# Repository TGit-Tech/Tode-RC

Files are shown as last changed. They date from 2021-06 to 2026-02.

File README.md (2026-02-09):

-----------------------------------------------------------------------------------
# Tode-RC
-----------------------------------------------------------------------------------
A User-Interfaced Arduino Mega Pro with Ebyte LoRa Radio.\
It's like a RF-Node but call it a 'Tode'.

- Arduino Mini Mega 2560 compatible Micro-Controller
- 1.8" TFT Display and 6-Button Keypad
- User friendly On-Controller IO configuration

See the docs/ Users-Guide for device support list and usage details including MQTT OpenHab connection abilities.

Benefits of the Tode over ESP32 LoRa Modules
- Big enough to be practical.  Small enough to be handy.
- 5V TTL-IO (Ebyte-RF 5V match, 200mW/IO power, Ready-fit for 5V Sensors)
- 54-IO pins (leaving (46) with display, keypad, radio connected)
- 30dbm (T30D) Transmission Power with Ebyte LoRa Modules (A good 5-mile distance)
- 3-Piece plug-together assembly keeps individual parts easy to swap/salvage.

Due to button sticking issues the buttons are now just black tops shown in first image.

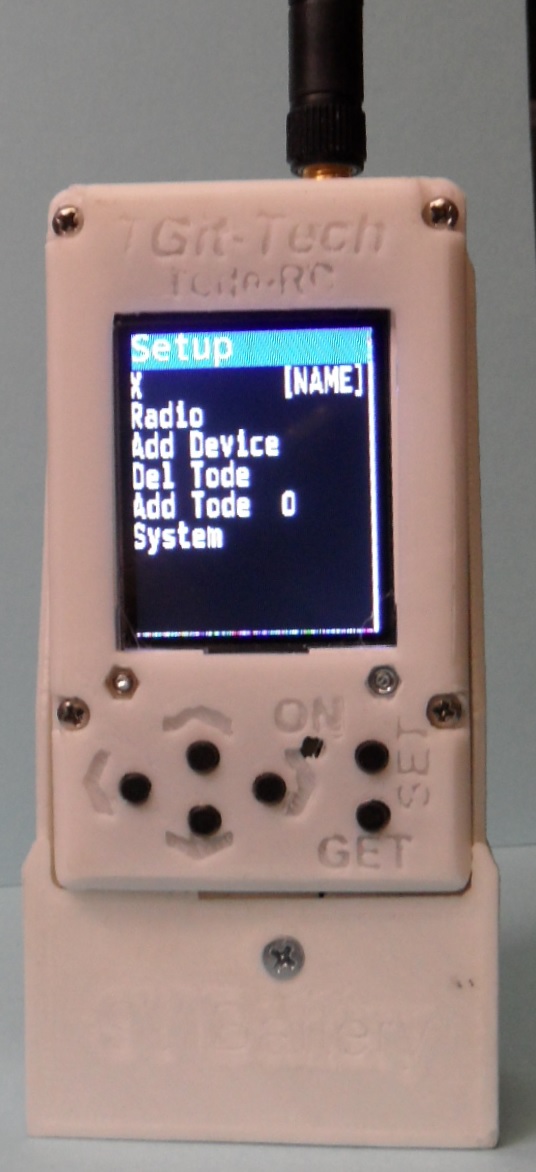
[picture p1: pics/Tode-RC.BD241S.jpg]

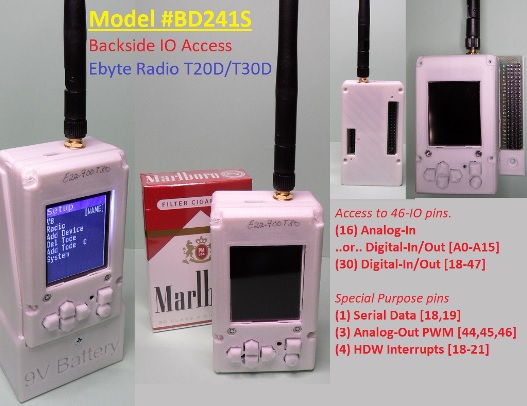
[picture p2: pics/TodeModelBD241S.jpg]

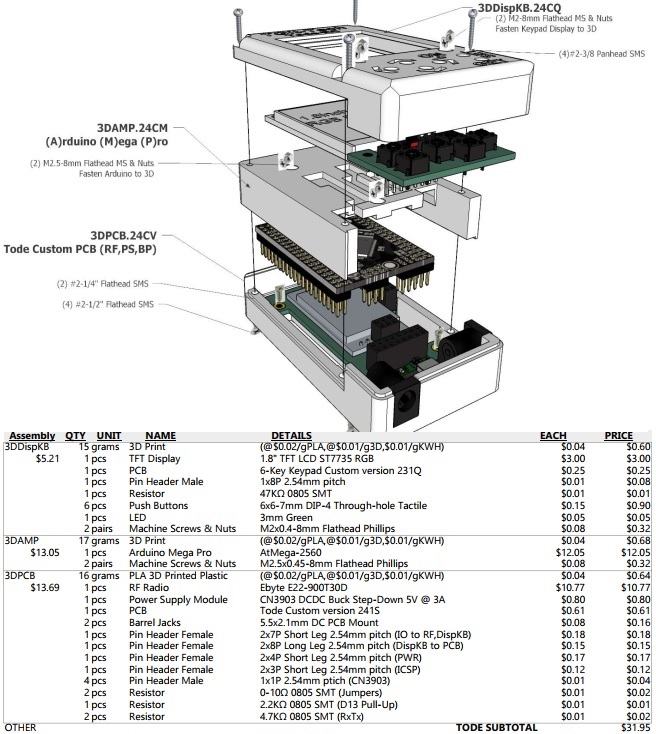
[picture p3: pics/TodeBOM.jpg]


-----------------------------------------------------------------------------------
#Project Purchase Options
-----------------------------------------------------------------------------------
Purchase pre-made at...
- https://www.tindie.com/stores/tgittech/
- https://www.etsy.com/shop/TGitTech

-----------------------------------------------------------------------------------
#Project Firmware & Expansions
-----------------------------------------------------------------------------------
- Firmware at https://github.com/TGit-Tech/Tode-RC-Firmware
	- Be sure to set Backplane model in config.h
- Side-IO Screw Terminals #SIOST (pictured) https://github.com/TGit-Tech/Tode-IO
- Back-IO Pin Header Array #BIOPH https://github.com/TGit-Tech/Tode-IO

-----------------------------------------------------------------------------------
#Project Status
-----------------------------------------------------------------------------------
USE Tode-RC.BD241S.  It supports 1W(T30D) or 1/4W(T20D) Ebyte Radios.\
Double Check that the PCB doesn't have the below design error.

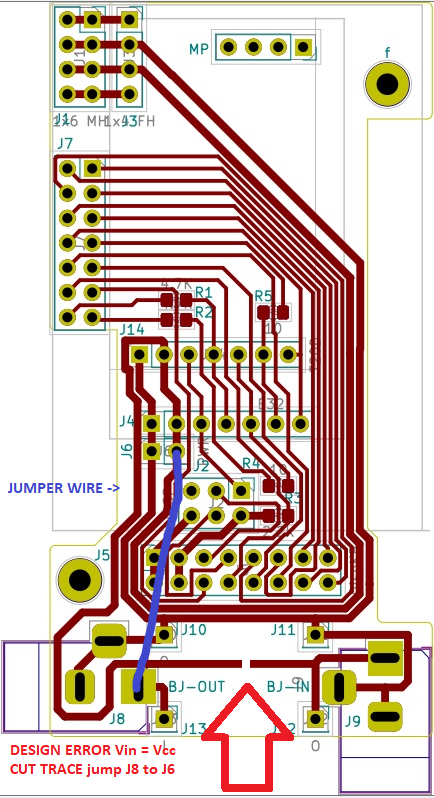
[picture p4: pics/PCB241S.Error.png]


Model SD23CF(In-Design/BETA) supports 2W(T33D) Radios but only 7-IO pins.
	
- Previous Release Notes
NEW changes.  The old model SA212K with analog keypad will become obsolete (not supported).
All future designs will have digital keypads as analog was spotty with moisture and 
temperature change.  Secondary Power Supplies are On-PCB now for both SD23CF(Side-IO) 
and BD241S(Back-IO).  Firmware will auto-detect E32-433T20D/T30D, E22-400T30D/900T30D 
and E220-400T30D Ebyte Radios.

---

# 🌐 **Tode Ecosystem**

The Tode Ecosystem offers a robust, flexible, and secure solution for managing devices in an environment where **infrastructure is not required**. It’s designed to seamlessly integrate with the **RF-DITS** protocol, providing a communication framework for device control, alarm propagation, and security.

## 🚀 **Overview**

The Tode Ecosystem empowers devices to function autonomously or in **P2P** (peer-to-peer) networks, providing an **infrastructure-free solution** for industrial, home, and remote applications. With its **5V EMT-resistant hardware** and powerful **virtual device** logic for alarm processing, it brings resilience and versatility to the edge of your network.

---

## 🛠️ **Key Features**

* **Non-Infrastructure Communication**: Operates **without** requiring an internet connection, server, or cloud dependencies. Devices communicate **peer-to-peer** between nodes, allowing for seamless data exchange and control.

* **RF-DITS Protocol**: The core communication protocol used by the Tode ecosystem. This protocol allows secure, fast, and efficient communication between Master and Remote nodes using **Device Index Tables (DIT)** with integrated security.

* **5V EMT Resistance**: Built to handle harsh environments, the Tode ecosystem is engineered to withstand **electromagnetic interference (EMI)**, providing reliable operation in industrial settings.

* **Virtual Device Logic**: The **Virtual Device Logic** allows users to implement custom control logic directly on the device, enabling real-time alarm processing, device manipulation, and other control functions.

* **Quick Firmware Updates**: The firmware can be quickly updated by plugging the Tode node into a wiring interface, making updates straightforward without requiring specialized equipment.

---

## 🔒 **Security**

* **SecNet (Security Network)**: The Tode ecosystem utilizes **SecNet**, a user-set security code embedded in each packet. This ensures data integrity and security. The **SecNet** code is also used as part of a challenge-response mechanism during **SETVAL** operations, preventing replay attacks and ensuring secure value updates.

* **Packet Integrity**: Every packet transmitted in the Tode network is verified for authenticity with the **SecNet** code. Only authorized devices can send or receive data securely. **SETVAL** operations are particularly secured to ensure legitimate communication.

* **Alarm Security**: Alarm messages are pushed to the designated **Remote nodes** when a condition is triggered. The **SecNet** code ensures that only authorized recipients receive the alarm notifications.

---

## ⚡ **Quick Setup & Control**

* **Device Setup**: The Tode ecosystem doesn’t require centralized infrastructure or cloud servers. Each **Master node** stores the configuration of its attached devices and is capable of sharing this configuration with **Remote nodes** using the **RF-DITS protocol**. **Remote nodes** can pull configurations and control devices according to those settings.

* **Time-Sensitive Updates**: Alarm conditions are pushed immediately to all **Remote nodes** without unnecessary overhead. Value updates can be requested by the remote node through the **RF-DITS protocol**, ensuring efficient communication.

---

## 📈 **Key Advantages Over Common IoT Platforms**

| **Key Advantage** | **Tode Ecosystem (RF-DITS)** | **Common IoT Platforms** |
| --- | --- | --- |
| **Infrastructure** | Operates **without** internet or server dependencies, functioning in **peer-to-peer** mode. | Requires cloud, servers, or centralized hubs for device control |
| **Portability** | **Portable** control with remote nodes in P2P communication. | Typically dependent on fixed infrastructure |
| **Data Integrity** | Secured communication with **SecNet** protecting packets and ensuring valid data exchange. | Often lacks robust security or packet verification |
| **Low Airtime Communication** | Optimized communication with **DIT** table, reducing airtime usage for value exchanges. | Typically uses more airtime due to polling systems and continuous communication |
| **Alarm Handling** | **One-time push** of alarms to Remote nodes, minimizing network traffic. | Continuous polling for alarm conditions, leading to higher network usage |
| **Device Control** | Full **control** over devices with direct value setting, updating, and logic processing. | Remote devices may be read but not easily controlled depending on the platform  |
| **EMT Resistance** | Designed to handle **electromagnetic interference (EMI)** in industrial environments. | Sensitive to environmental EMI interference, which can disrupt performance |
| **Firmware Updates** | **Easy and fast** firmware updates via a wiring interface—no internet or specialized equipment needed. | Over-the-air updates typically require internet access and cloud dependencies |
| **Flexible Control Logic** | **Virtual device logic** allows for custom control and alarm processing locally on the device. | Often lacks flexibility for local control and relies on cloud logic |

---

## ⚙️ **Protocol Breakdown: RF-DITS**

### **Device Index Table with Security (DITS)**

Each node maintains a **Device Index Table (DIT)** that lists the connected devices by index. This table helps the **Master node** store and transmit configurations for each attached device to **Remote nodes**.

* **Master Node**: Stores and manages the configuration of devices, pushes alarm notifications, and shares device settings with **Remote nodes**.
* **Remote Node**: Pulls device configurations from the **Master node** and can manipulate values according to the stored configuration.

### **Alarms**

* **Alarm Handling**: When an alarm condition is triggered on the **Master node**, an alarm packet is sent to all **Remote nodes** on the recipient list.
* **No Acknowledgment Required**: The alarm is a **one-time push** with no response required from the **Remote nodes**.
* **Alarm Recipient List**: The **Master node** stores a list of **Remote node** addresses, which is dynamically updated with each communication, including value requests. Manual pruning of the list is also possible.

---

## 🔗 **Integration with External Systems**

While the Tode ecosystem operates **without the need for internet infrastructure**, it can optionally integrate with systems such as **MQTT**, **OpenHAB**, or **Home Assistant** through an MQTT bridge.

This optional feature allows:

* **Pulling Device Values**: Remote nodes can request device values from **Master nodes** on a regular schedule or based on events.
* **Pushing Alarms**: When an alarm condition is triggered, the **Master node** can push the alarm data to an MQTT broker, which allows external systems to act on the alarm.

However, it's important to note that **Tode's core functionality** works without cloud connectivity, and the MQTT integration is entirely optional.

---

## 🔑 **Hardware Advantages**

Tode nodes are designed to operate in **industrial environments** where **electromagnetic interference (EMI)** is common, and devices need to withstand harsh conditions. The **5V EMT-resistant hardware** ensures the Tode ecosystem works reliably even in settings that may disrupt other IoT systems.

---

## 🛠️ **Getting Started**

1. **Set Up the Master Node**: Connect and configure devices on the **Master node**. Store configurations and define which devices you want to control.
2. **Add Remote Nodes**: Manually enter the **Master node's** address into the **Remote nodes** to establish communication and pull device configurations.
3. **Manage Alarms and Control**: Configure alarm conditions on the **Master node**. Alarms will be **pushed** to all **Remote nodes**.
4. **Firmware Updates**: Simply plug the Tode node into the wiring interface to update its firmware without requiring internet access.

---

## 📚 **Conclusion**

The **Tode Ecosystem** offers a resilient, flexible, and secure solution for edge-device control in environments where **infrastructure** is not an option. Its core **RF-DITS protocol** and **5V EMT resistance** provide reliable communication, while its optional integration with systems like **MQTT** makes it versatile for a range of applications.

---

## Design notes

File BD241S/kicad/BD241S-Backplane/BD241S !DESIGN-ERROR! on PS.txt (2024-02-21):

The Input voltage traces to VCC.
It can be cut and then add a jumper wire from P.S. out to VCC.

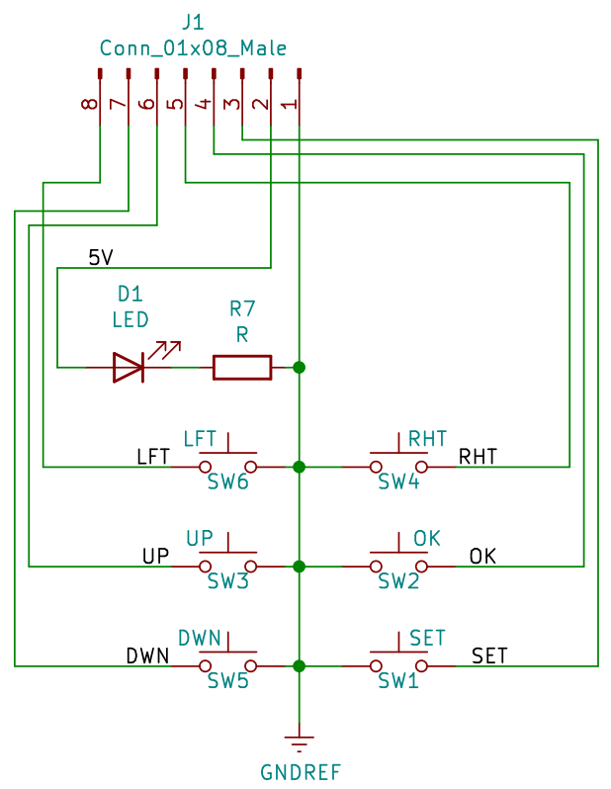
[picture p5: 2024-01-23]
BD241S/kicad/Tode-Buttons-D231Q/Schematic.png

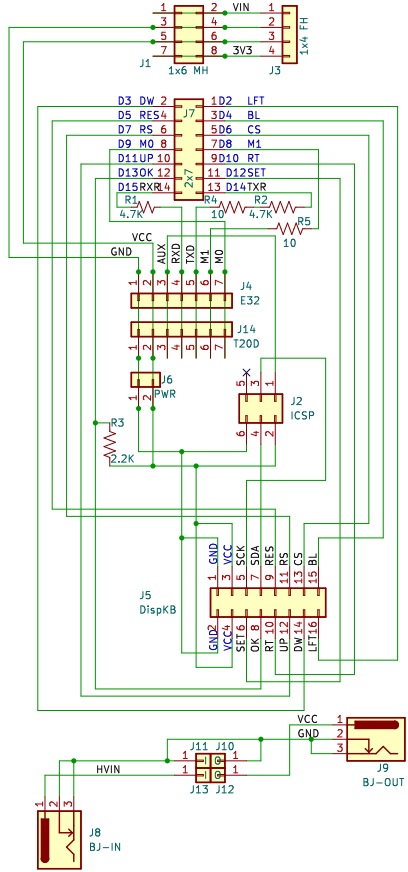
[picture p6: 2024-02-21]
BD241S/kicad/BD241S-Backplane/241S-Schematic.jpg

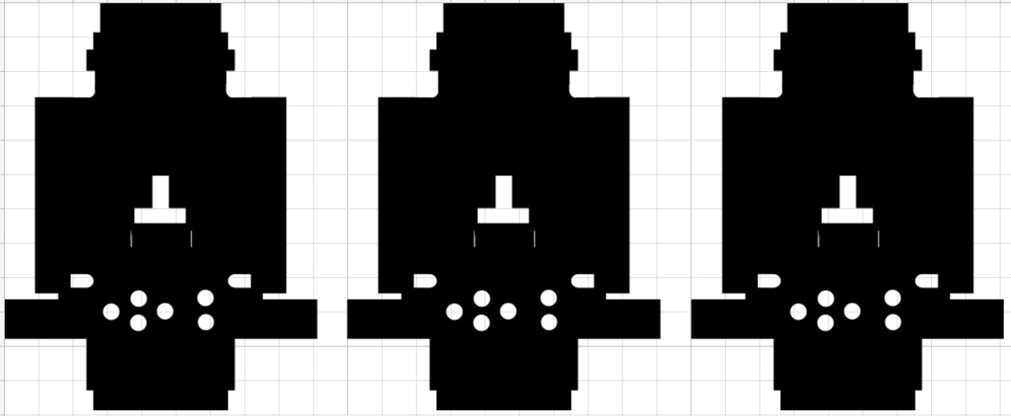
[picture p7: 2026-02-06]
docs/CriCut-Decal-Laminate.jpg

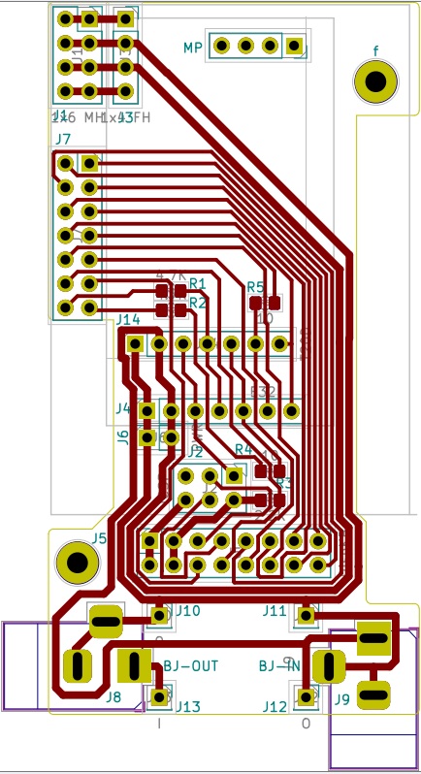
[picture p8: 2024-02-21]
BD241S/kicad/BD241S-Backplane/241S-Layout.jpg

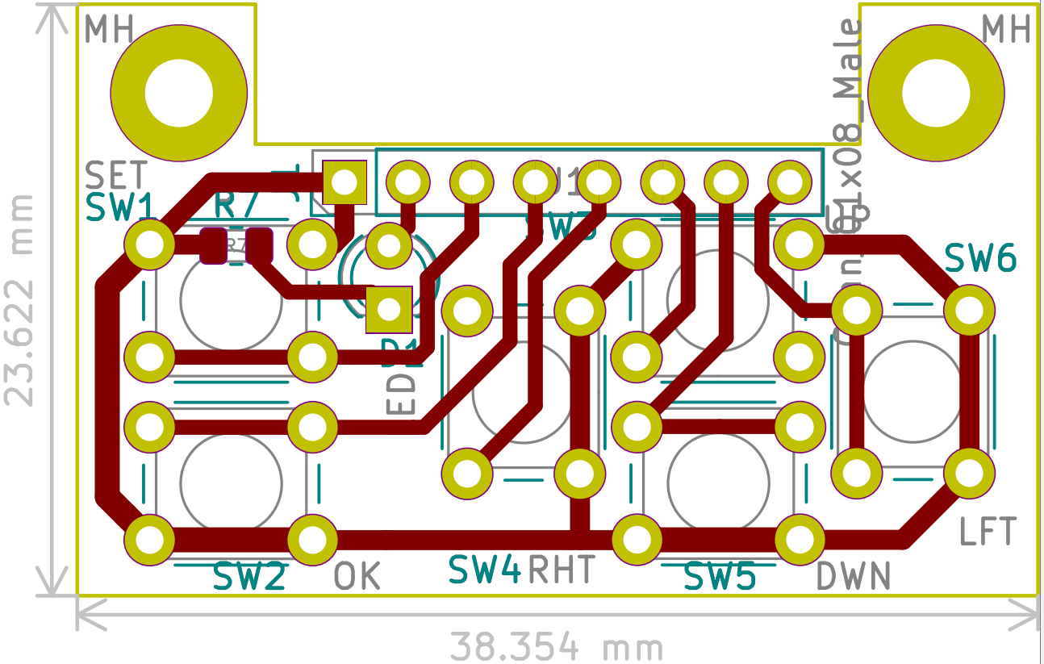
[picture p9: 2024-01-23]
BD241S/kicad/Tode-Buttons-D231Q/Layout.png

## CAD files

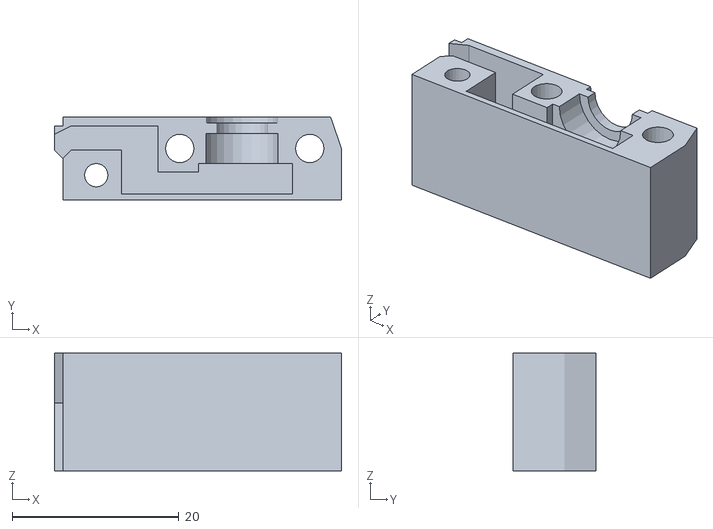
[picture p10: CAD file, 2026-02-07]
BD241S/3DPrints/9V1W.3DClamp.24CV.stl
34.4 x 10.0 x 14.1

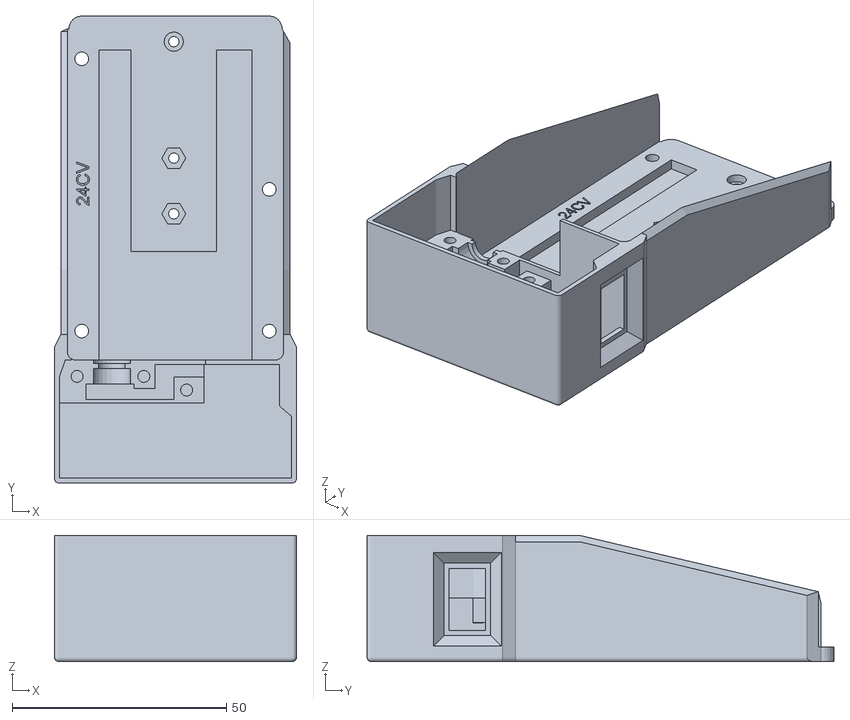
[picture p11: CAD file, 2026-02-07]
BD241S/3DPrints/9V1W.3DTray.24CV.stl
56.5 x 109.1 x 29.5

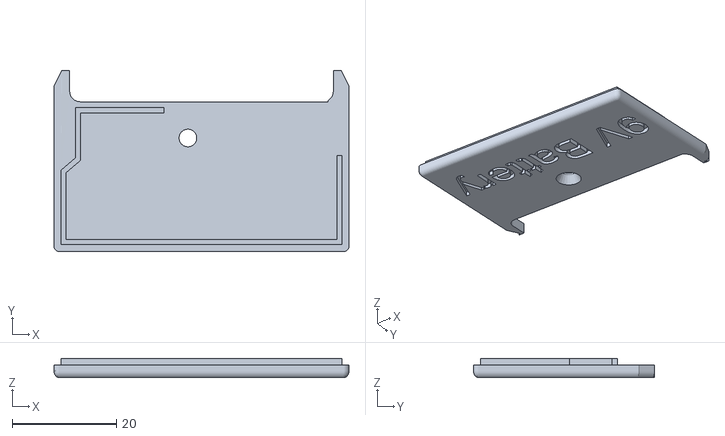
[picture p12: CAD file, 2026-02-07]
BD241S/3DPrints/9V1W.3DCover.2627.stl
56.6 x 34.7 x 3.70

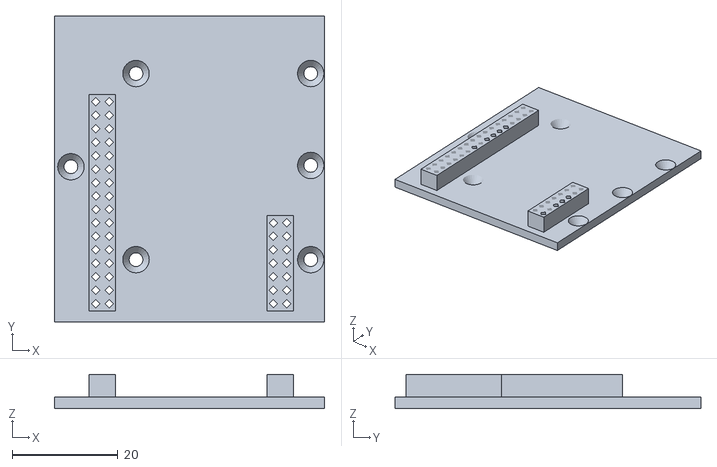
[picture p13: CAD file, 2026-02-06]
BD241S/3DPrints/BIOPH.FrontSide.249Q.stl
51.0 x 57.8 x 6.50

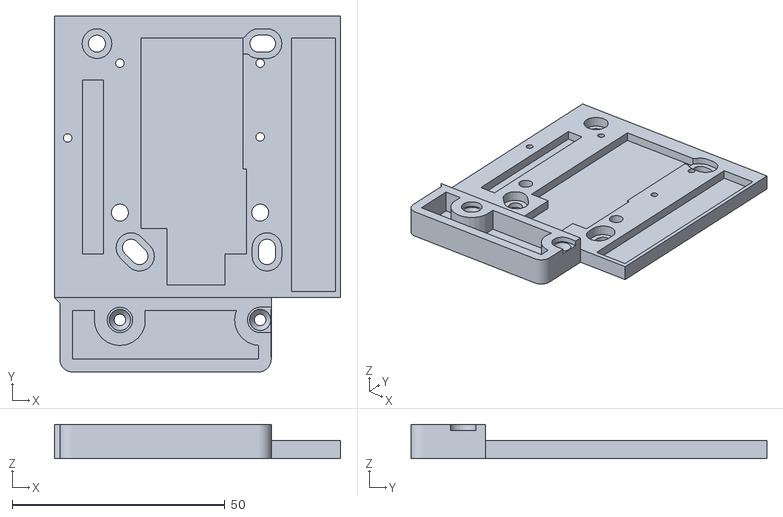
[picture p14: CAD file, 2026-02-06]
BD241S/3DPrints/BIOPH.BackSide.261C.stl
67.3 x 83.8 x 8.06

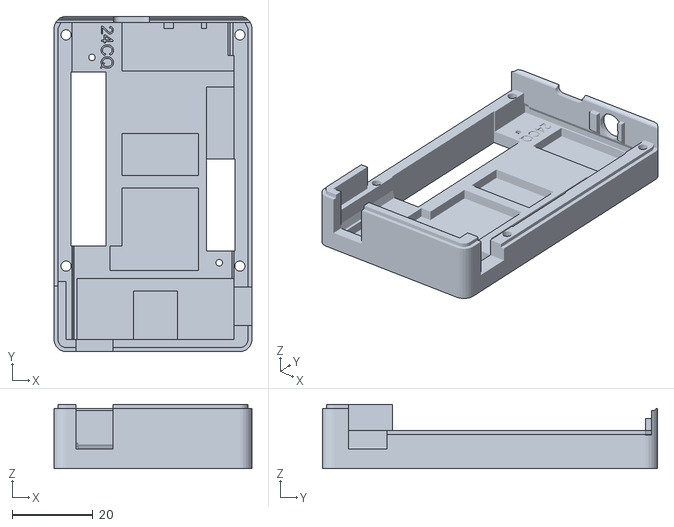
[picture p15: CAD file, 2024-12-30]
BD241S/3DPrints/BD241S.3DPCB.24CQ.stl
49.0 x 83.0 x 15.9

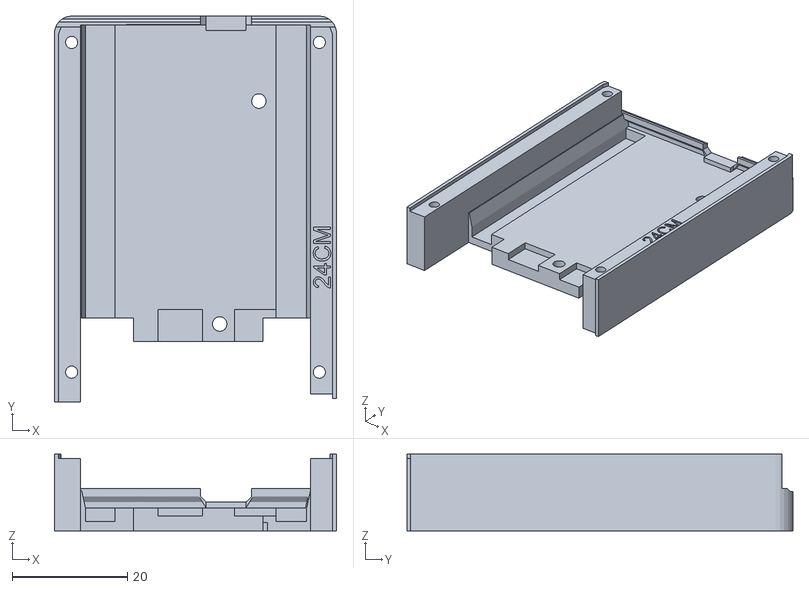
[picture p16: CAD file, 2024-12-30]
BD241S/3DPrints/BD241S.3DAMP.24CM.stl
49.0 x 67.0 x 13.4

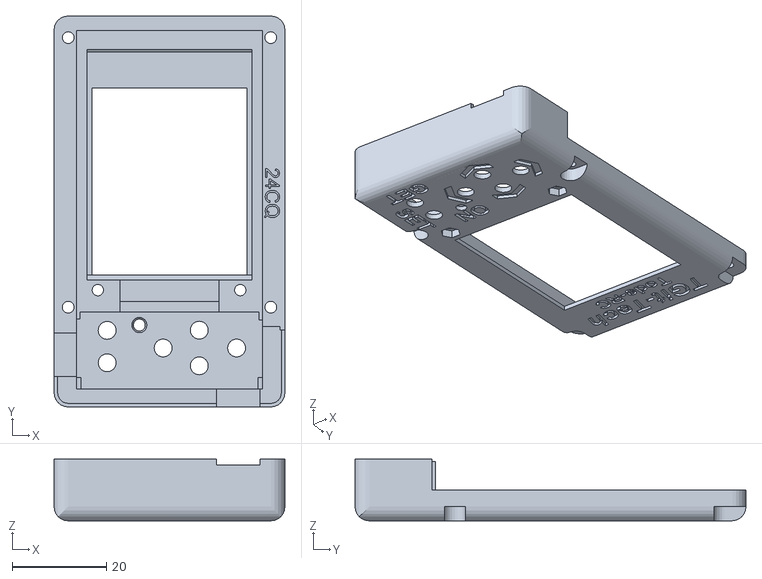
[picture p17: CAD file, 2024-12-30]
BD241S/3DPrints/BD241S.3DDispKB.24CQ.stl
49.0 x 83.0 x 13.1

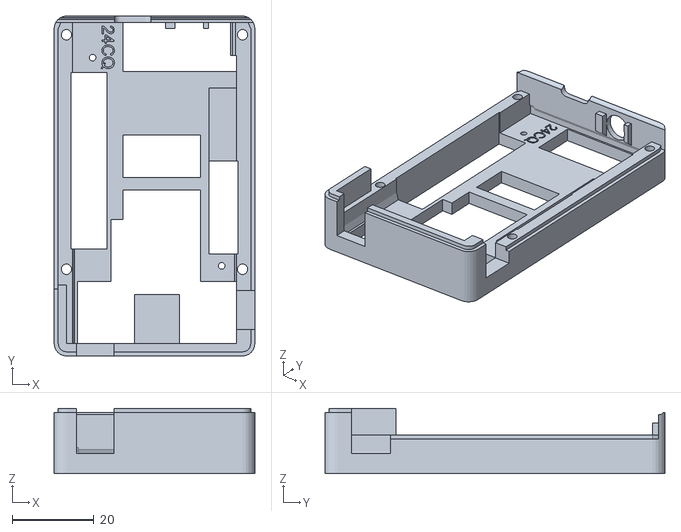
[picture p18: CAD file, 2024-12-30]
BD241S/3DPrints/TOOL.3DPCBSolderAlign.24CQ.stl
49.0 x 83.0 x 15.9

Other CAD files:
BD241S/3DPrints/skp/9V1W.3DClamp.24CV.skp
BD241S/3DPrints/skp/9V1W.3DCover.2627.skp
BD241S/3DPrints/skp/9V1W.3DTray.24CV.skp
BD241S/3DPrints/skp/BD241S.3DAMP.24CM.skp
BD241S/3DPrints/skp/BD241S.3DAssembly-Diagram.skp
BD241S/3DPrints/skp/BD241S.3DAssembly.skp
BD241S/3DPrints/skp/BD241S.3DDispKB.24CQ.skp
BD241S/3DPrints/skp/BD241S.3DPCB.24CQ.skp
BD241S/3DPrints/skp/TOOL.3DPCBSolderAlign.24CQ.skp

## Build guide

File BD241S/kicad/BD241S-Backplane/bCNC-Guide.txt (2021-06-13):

QUICK GUIDE
notation = [Menu-bar].{section}/=Ribbon=."Button"
----------------------------------------------------------------------------
1.	Run bCNC
2.	[FILE].{Serial}.set-COM."Open"
3.	[CONTROL].{Status}."XYZ=0"
4.	[CONTROL].{Command}."G01 X22Y17 F300" ( variations - see #3 below )
6.	[CONTROL].{Control}."Z-down" till bit is close but not touching PCB
5.	[CONTROL].{Status}."XYZ=0"
4.	[PROBE].{Probe}."Probe"			( Req setup parameters first )
5.	Wait for 'Idle' then [CONTROL].{Status}."XYZ=0"
6.	[OPEN-FILE]icon.open-file
7.	[PROBE].=Autolevel=."Margins"
8.	[PROBE].{Autolevel} Set number of probes X & Y for ~ Step of 12
9.	[PROBE].=Autolevel=."Scan" (Big Button)
10.	Wait for 'Scan' to finish
11.	[PROBE].=Autolevel=."Zero"
12.	De-Wire the bit
13.	[CONTROL]."Start"
------------------------------------------------------------------
1. [CONTROL]  	Home + XYZ=0 + "G01 X22Y17 F300" + Z-Down-Close + XYZ=0
2. [PROBE]		Probe + XYZ=0												Probe Feed: 5.0
3. Load the File + Autolevel Margins + Scan									Z: Max: 0.5

vvvvvvvvvvvvvvvvvvvvvvvvvvvvvvvvvvvvvvvvvvvvvvvvvvvvvvvvvvvvvvvvvvvvvvvvvvvvvvvvvvvvvvvvvvvvvvvvvvv
1.  Setup
  a - Load a blank PCB onto the CNC Mill using 3D Printed Platform:
      "D:\Mechanical\ME - CNC-Milling\PCB-Mill-Platform\PCB-MillPlatform-100x70mm-Smoothed.stl"
  b - Load the Bit used for Trace Isolation
  c - Connect the Probe Wires to the Board and Bit
  d - Power up the CNC Mill
  e - Start bCNC

2.  Connect
  a - MENU 'File'
      -- 'Serial' -> 'Open'
      -- Check 'Connected' status & Positions are shown

3.  Homing
  a - MENU 'Control'
      -- Click 'Custom Button #5' or Command '$h'
      -- Click 'XYZ=0'
      -- In 'Command' Box (bottom-left) enter 'G01 X22Y17 F300'
          TEMP SPOT: 'G01 X57Y42 F300'
          -- Tightest X & Y = G01 X21.5Y16 F300
          -- Tightest X = G01 X21.5Y17 F300
          -- Tightest Y = G01 X22Y16 F300
      -- Click 'XY=0'
      -- Under 'Control' Press Z-Down 30
      -- VISUALLY check bit is in a good XY=0 position

4. Initial Z-Probe
  a - MENU 'Probe' - SUBMENU 'Common'
      -- Fast Probe Feed: 	100.0
	  -- Probe Feed: 		10.0
	  -- TLO:				0.000
	  -- Probe Command:		G38.2
  b - MENU 'Probe' - SUBMENU 'Probe'
      -- Set last box (Probe along Z-axis):   -10
      CLICK 'Probe'
      -- Click 'Z=0'
  
9. Open File
  a - MENU 'Open File' (Small folder icon top-left)

10. Autolevel Probe
  [[ PROBE - AutoLevel - Margins - Scan & PROBE - Probe - AutoLevel - Zero ]]
  a - MENU 'Probe' - SUBMENU 'Autolevel'
      -- Click 'Margins'
      ++ Under 'AutoLevel'
        -- Set 'N' for probes per Row/Col on the PCB
        -- Click 'Scan' (NOT the small next to Margins but the BIG ONE!)

  b - MENU 'Probe' - SUBMENU 'Probe'
      -- Click 'Probe'
      
  c - MENU 'Probe' - SUBMENU 'Autolevel'
      -- Click 'Zero' (Under Margins at Top Submenu)
      
11. Remove Probe Wires

12. Start Milling
  a - MENU 'Control'    (optionally start spindle beforehand with 'M03 S2000')
      -- Click 'Start'

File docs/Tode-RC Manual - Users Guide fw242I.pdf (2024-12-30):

# Tode-RC

# Users Guide

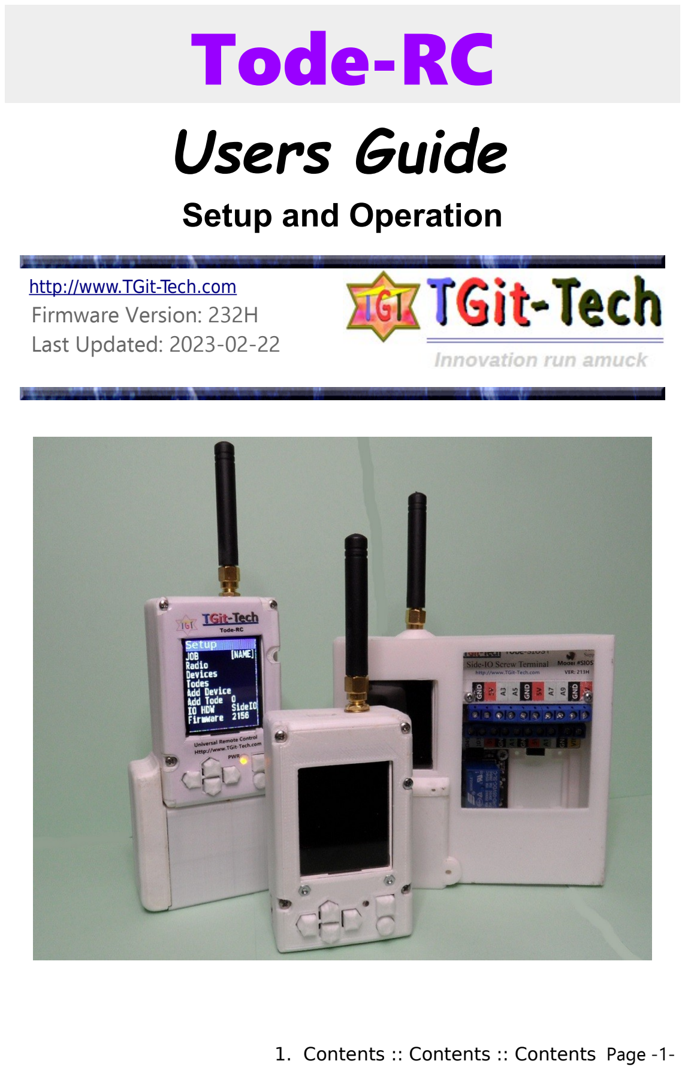
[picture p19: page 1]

## Setup and Operation

http://www.TGit-Tech.com

### Firmware Version: 232H Last Updated: 2023-02-22

1. Contents :: Contents :: Contents Page -1-

## 1. Contents

## Table of Contents

A. MQTT /get Value Update ........22
1. Contents :: Contents :: Contents Page -2-

## 2. Introduction

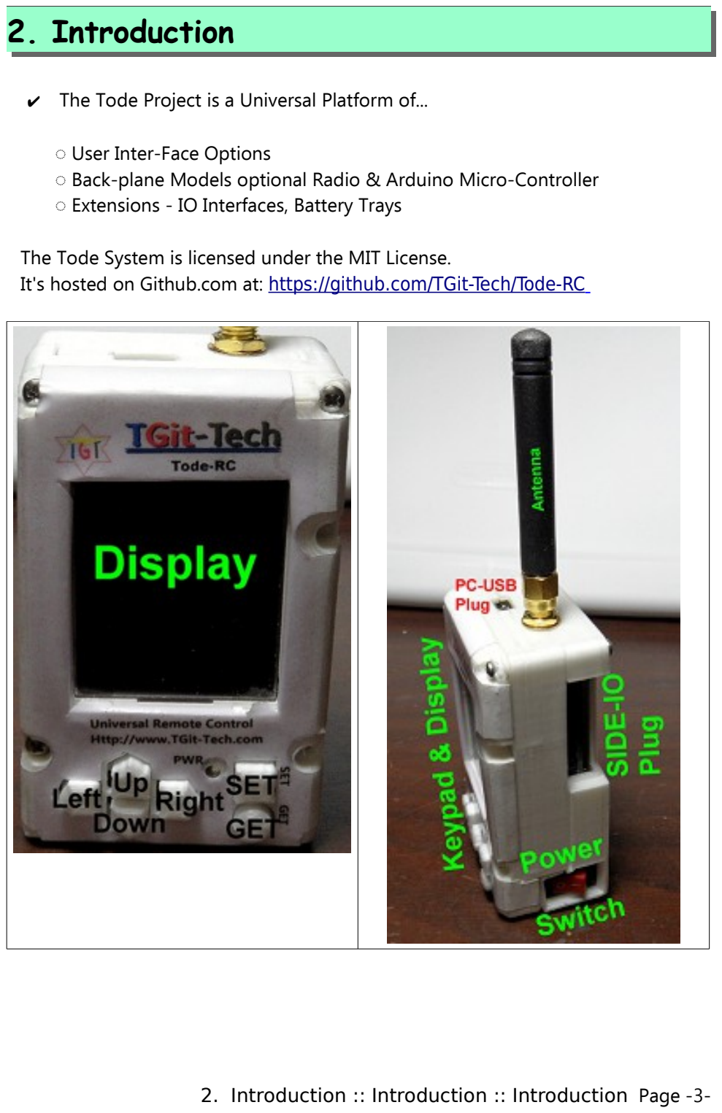
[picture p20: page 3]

✔ The Tode Project is a Universal Platform of...

◌ User Inter-Face Options
◌ Back-plane Models optional Radio & Arduino Micro-Controller ◌ Extensions - IO Interfaces, Battery Trays

The Tode System is licensed under the MIT License.
It's hosted on Github.com at: https://github.com/TGit-Tech/Tode-RC
2. Introduction :: Introduction :: Introduction Page -3-

### 2.1 Specifications

✔ Remote-Control Tested Distance
◌ Test Setup
- (2) Todes set at Tx Power 30dbm
- (2) Todes having a 5dbi 20cm Omni antenna
- Stationary Tode antenna mounted 12ft above ground level
- Rural Area.
◌ Signal can reasonably be used at 2-miles away
◌ Signal can be spot gotten (hard to get) at 3-miles away
◌ There is no signal past 3-miles

2.1 Introduction :: Specifications :: Specifications Page -4-

### 2.2 Menu Structure

✔ Multiple Todes make-up a remote-control network-of Individual Todes.

◌ The particular Tode in subject is self-described as This-Tode.
◌ Each Tode that is accessible on This-Tode has its own Tode-Screen.

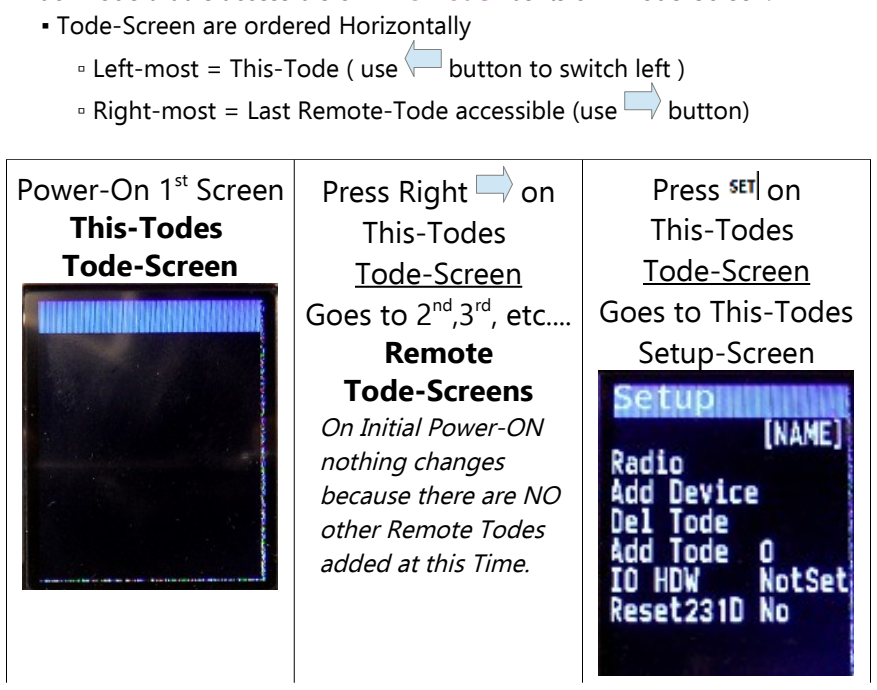
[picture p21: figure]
▪ Tode-Screen are ordered Horizontally; Power-On 1st Screen This-Todes Tode-Screen; Press Right; This-Todes Tode-Screen Goes to 2nd,3rd, etc.... Remote Tode-Screens On Initial Power-ON nothing changes because there are NO other Remote Todes added at this Time.; Press on This-Todes Tode-Screen Goes to This-Todes Setup-Screen

- Left-most = This-Tode ( use | button to switch left )
- Right-most = Last Remote-Tode accessible (use | button)

✔ Sub-Level Menu Screens ( From This-Todes SETUP Screen )
◌ Selecting Radio and | will produce Sub-Level Radio Settings.
◌ Selecting Add Device and | will produce Add a Device Screen.
◌ Selecting Del Tode and | will produce List of Todes.
◌ To Exit a Sub-Level Screen press the | button.

2.2 Introduction :: Menu Structure :: Menu Structure Page -5-

GET
GET
GET

## 3. Configure

### 3.1 Set Name

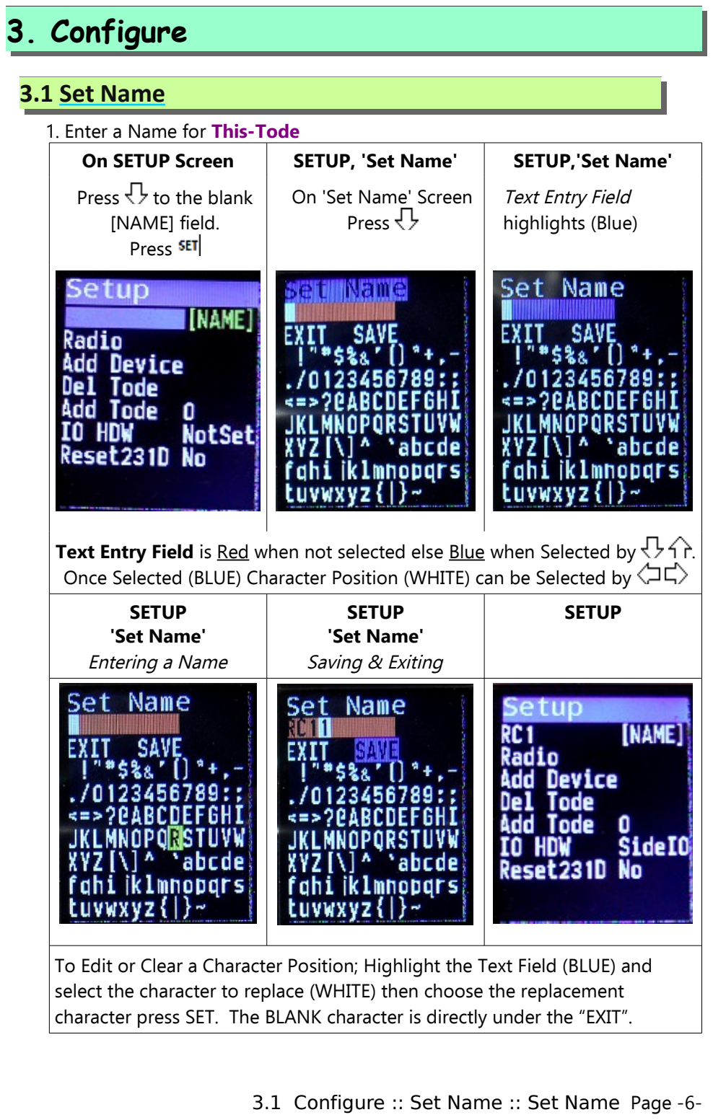
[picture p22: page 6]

1. Enter a Name for This-Tode
On SETUP Screen | SETUP, 'Set Name' | SETUP,'Set Name'
Press | to the blank
[NAME] field. Press | On 'Set Name' Screen Press | Text Entry Field highlights (Blue)
Text Entry Field is Red when not selected else Blue when Selected by | .
Once Selected (BLUE) Character Position (WHITE) can be Selected by
SETUP
'Set Name'
Entering a Name

SETUP
'Set Name'
Saving & Exiting

SETUP

To Edit or Clear a Character Position; Highlight the Text Field (BLUE) and select the character to replace (WHITE) then choose the replacement character press SET. The BLANK character is directly under the “EXIT”.

3.1 Configure :: Set Name :: Set Name Page -6-

### 3.2 Radio Settings

### 3.2.1 Requirements

✔ Radio Settings that must be identical for Tode Communication. SecNet
(Range 01-7F)

Security Code selected by you that prevents unauthorized access to your Tode network.
Frequency
(410 to 441)MHz

The radio frequency (channel) for Tode Communication.

✔ Radio Setting that must be Unique Address
(Range 0000-FFFE)

A radio address to identify each Tode uniquely decided upon by you.

✔ Other Radio Settings
Tx Power
(21,24,27,30)dBm

Sets the (Tx) Transmitting Power of the Radio. Lower saves power, Higher transmits farther.
PC Connex
(On -or- Off)

When set to On it ties the radio terminal to the USB Port. This a special function generally ignored by users.

### 3.2.2 Per-Digit Setting

1. Choose any SecNet Value between 01 to 7F and Set that Value.
SETUP | SETUP
RADIO

SETUP
RADIO (Per-Digit Set)
to select Radio.
Press

to select SecNet
to select Value
Press | to change.
Press | again to set.

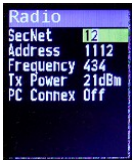
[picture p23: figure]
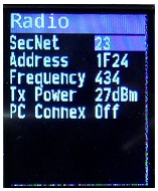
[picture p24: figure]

SecNet and Address use Per-Digit Set where each digit is changed at a time.
The WHITE background indicates the selected digit. Use | to change
the selected digit and | to change the digits value. Going | beyond
the number of select-able digits will exit setting without saving changes.

3.2.2 Configure :: Radio Settings :: Per-Digit Setting Page -7-

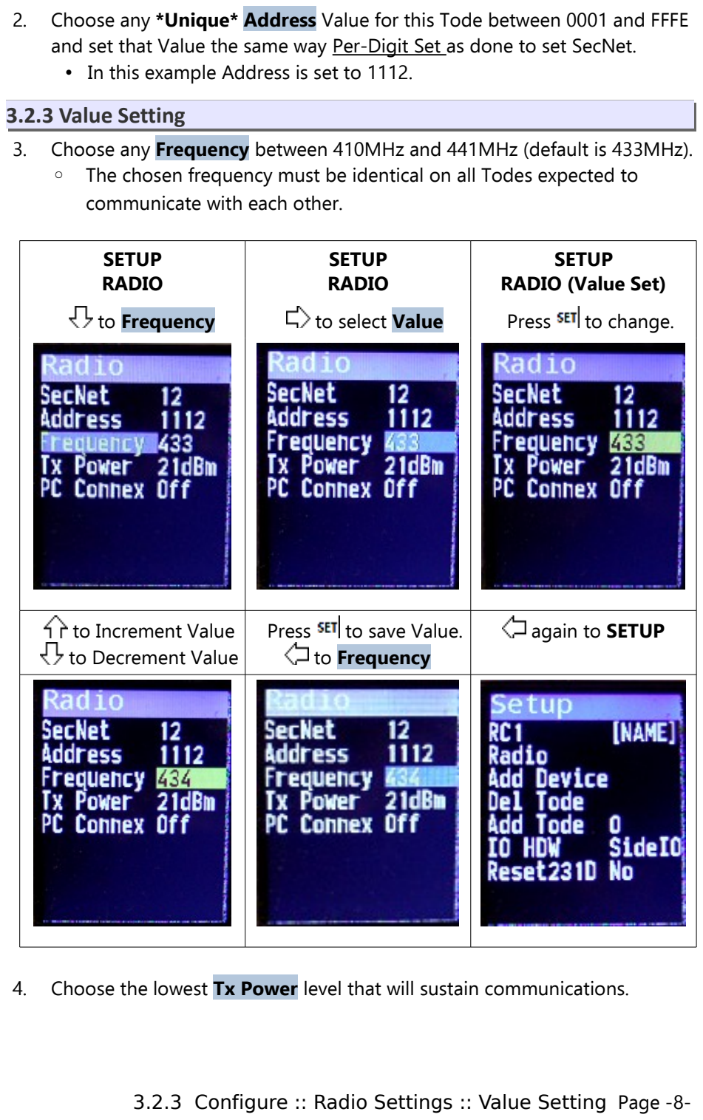
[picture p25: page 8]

2. Choose any *Unique* Address Value for this Tode between 0001 and FFFE and set that Value the same way Per-Digit Set as done to set SecNet.
- In this example Address is set to 1112.

### 3.2.3 Value Setting

3. Choose any Frequency between 410MHz and 441MHz (default is 433MHz).
- The chosen frequency must be identical on all Todes expected to communicate with each other.

SETUP
RADIO

SETUP
RADIO

SETUP
RADIO (Value Set)
to Frequency | to select Value | Press | to change.

to Increment Value
to Decrement Value

Press to save Value. to Frequency

again to SETUP

4. Choose the lowest Tx Power level that will sustain communications.

3.2.3 Configure :: Radio Settings :: Value Setting Page -8-

### 3.3 IO HDW Setting

1. A Tode that has connected devices must know what IO HDW is used to connect the devices. If the Tode will be used only as a hand-held control device, then setting the IO HDW is not needed.
a) At the time of this writing the only option for connecting devices is a SideIO Plug (SIOST stands for SideIO with Screw Terminals).
SETUP | SETUP | SETUP
to IO HDW | to select Value (I.e. 'NotSet' in picture)
then | or
| | select SideIO to set the value

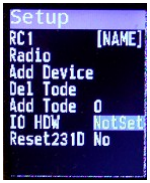
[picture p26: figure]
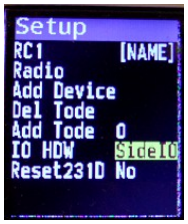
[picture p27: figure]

2. NOTICE: If the IO HDW has not been set before trying to set a device PIN the Tode will notify you with SetHDW as shown below.

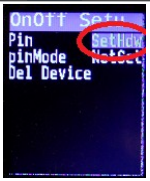
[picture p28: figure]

3.3 Configure :: IO HDW Setting :: IO HDW Setting Page -9-

### 3.4 Adding Devices

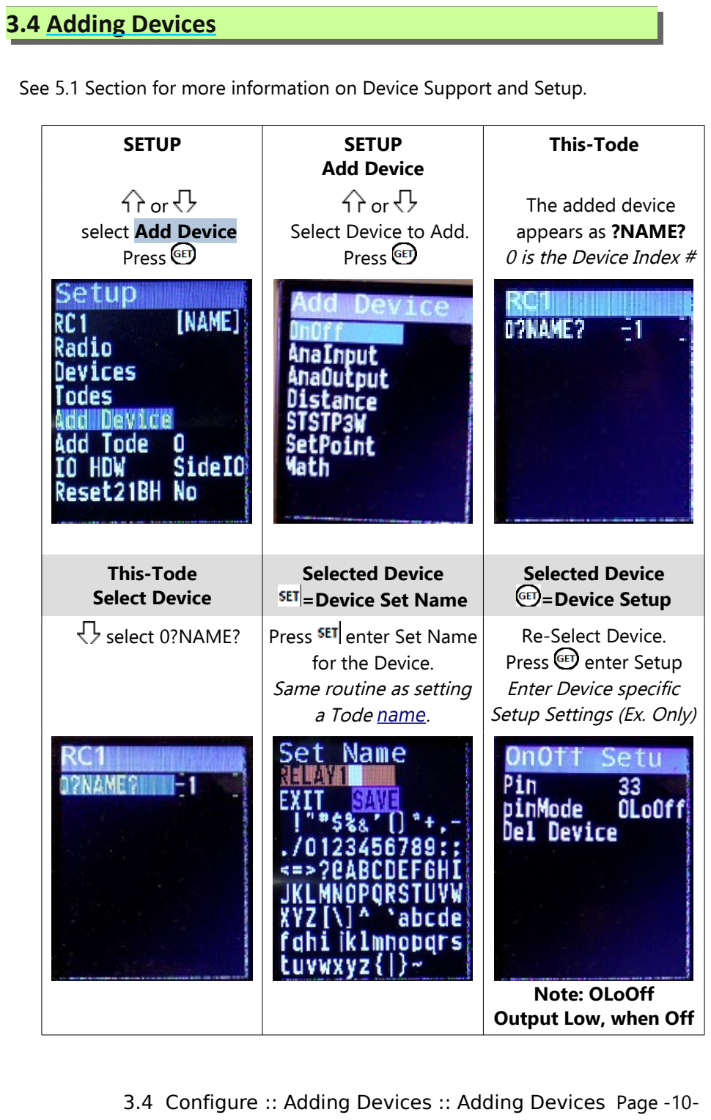
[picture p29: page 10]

See 5.1 Section for more information on Device Support and Setup.

SETUP | SETUP Add Device

This-Tode

or select Add Device Press | or Select Device to Add. Press

The added device
appears as ?NAME?
0 is the Device Index #

This-Tode
Select Device

Selected Device
=Device Set Name

Selected Device
=Device Setup
select 0?NAME? | Press | enter Set Name
for the Device.
Same routine as setting
| | a Tode name.

Re-Select Device.
Press enter Setup
Enter Device specific
Setup Settings (Ex. Only)

Note: OLoOff
Output Low, when Off

3.4 Configure :: Adding Devices :: Adding Devices Page -10-

### 3.5 Device Control

Below shows an example of how to change an Output Device’s State.

This can be done on LOCAL (This-Tode) devices or devices on Remote Todes. To add a Remote Tode see 3.6.Add Tode (Remote)

NOTE: Remote Tode Devices will show a value of ‘?’ until the readings are requesting by pressing .

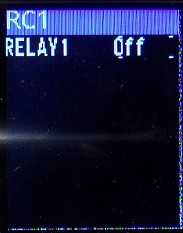
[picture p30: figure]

This-Tode | This-Tode | This-Tode
select RELAY1 to select Value Value 'Off' Press | to set a new value. change Value to set the value | Once set to 'On' Relay1 on pin 33 should activate.

3.5 Configure :: Device Control :: Device Control Page -11-

### 3.6 Add Tode (Remote)

✔ To Remotely Control another Todes Devices.
◌ The “Remote” Tode (RC1 with RELAY1:IO-Device used this far) ◌ is added to a new Tode (RC2)
✔ Obtain a 2nd Tode
◌ Repeat Steps 3.1.Set Name and Name the 2nd Tode RC2
◌ Assign a *Unique* Radio Address to RC2
RC2 Radio Settings | Required | RC1 Radio Settings
| SecNet has to Match.
| Address must be different / unique.
| Frequency has to Match.

On Tode RC2

add RC1 by Address Check for an RC1 “remote” Tode Screen.
select Add Tode | to select Value
to set RC1-Address

Again to load RC1
RC1 remote Screen

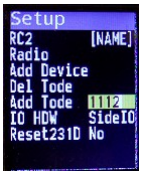
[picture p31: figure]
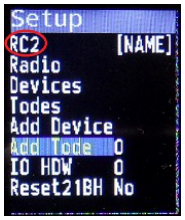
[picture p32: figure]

Now the Devices on RC1 can be controlled by RC2. If the “remote” Tode RC1 failed to show up; try again closer to the unit.

3.6 Configure :: Add Tode (Remote) :: Add Tode (Remote) Page -12-

### 3.7 Deleting

### 3.7.1 Deleting Devices

To Delete a Device enter the Device Setup Screen as shown in 3.4.Adding Devices and select Del Device and press .

### 3.7.2 Deleting Remote Todes

To Delete a Remote Tode control screen. Select Del Tode on the SETUP menu and then select the Remote Tode by Name on the list and press .

### 3.7.3 Factory Reset

Preforming a factory reset deletes the Tode Name and all Devices and Remote Todes. Radio Setting are preserved. To preform this operation…

select Reset????

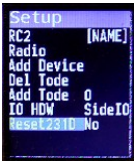
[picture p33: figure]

Note: The 4-Digit after
Reset is the Firmware
Version Loaded.

Firmware 231D

to select Value

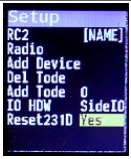
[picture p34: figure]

to set
to set Yes
again to apply.

The Tode will

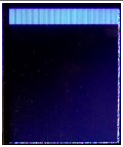
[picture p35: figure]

automatically Reboot
and the blank Tode
screen will show.

3.7.3 Configure :: Deleting :: Factory Reset Page -13-

## 4. IO Devices

### 4.1 Common Settings

✔ Every Device Setup has a Del Device option.

✔ Every Pin has a corresponding pinMode option. ◌ OLoOff = Output Low, when Off – Active High
◌ OHiOff = Output High, when Off – Active Low
◌ InHigh = Input Pull-Up(High) – Active Low
◌ InLow = Input Low – Active High (Default Setting)

### 4.2 OnOff

| On Off Device Setup Screen
Pin | Can be any Pin Selectable
pinMode | ptions in #4.1.Common Settings
Del Device | Select and to delete this device.

### 4.3 AnaInput

The equation for Value = (Pin-Reading + PreAdd) * (MultNum/MultDen) + Add. MultDen cannot be 0 so 0 equivocates to 10K (10,000)
| On Off Device Setup Screen
Pin | The Pin to read from (must be an ‘A’ pin)
pinMode
PreAdd | 1 st Add this amount to the Pin reading.
MultNum | 2 nd Multiply by fraction (Fraction Numerator)
MultDen | (Fraction Denominator)
Add | 3 rd Add after fraction multiply (i.e. offset value)
Samples | Number of reading to gather and average for value.

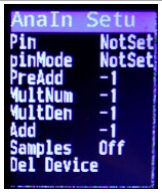
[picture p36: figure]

4.3 IO Devices :: AnaInput :: AnaInput Page -14-

### 4.4 AnaOutput

| AnaOutput is the PWM output operation
Pin | Analog Output is Always on PIN #45

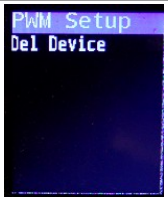
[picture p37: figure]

### 4.5 Distance

This is used for Sonic Distance Sensors with a Trigger & Echo Pins.

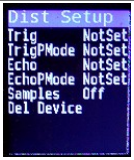
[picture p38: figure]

| Distance Device Setup Screen
Trig | The Trigger Pin
| The Trigger Pins pinMode
Echo | The Echo Pin
EchoPMode | Echo Pins pinMode
Samples | Number of Samples to Average for Value

4.5 IO Devices :: Distance :: Distance Page -15-

### 4.6 STSTP3W

This is used for panels with a START and STOP momentary push buttons.

| 3-Wire On/Off Momentary (3-second) Switch
StartPin | OUTPUT hat triggers to initiate a START button.
StartPMode | StartPin pinMode Setting
StopPin | The Pin that triggers to initiate a STOP button.
StopPMode | StopPin pinMode Setting
Status | INPUT; Pin that determines current state.
StatPMode | Status Pins pinMode
Del Device | Select and to delete this device.

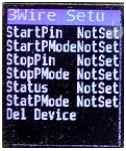
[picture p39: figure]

## 5. Automation (Logic)

### 5.1 SetPoint

Compares an Input Device reading to a User SetPoint and if the Input reading is outside the boundaries (+/- Tolerance) then it sets an Output Device respectively.

For example; A tank of water with a level sensor can maintain it’s water level by switching ON or OFF a pump that feeds the tank.

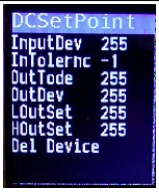
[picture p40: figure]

| On Off Device Setup Screen
InputDev | The Device Index to read a value from
InTolernc | The (+/-) tolerance allowed from setpoint
OutTode | The Tode Index of Out Device (optional) or 0-local
OutDev | The Device Index to SET the value on (optional)
LOutSet | SET value on OutDev when Input is < setpoint
HOutSet | SET value on OutDev when Input is > setpoint
| SET value can be ON or OFF
| Or INCR/DECR where Difference between setpoint

5.1 Automation (Logic) :: SetPoint :: SetPoint Page -16-

### 5.2 Math

Implements Mathematical Operation on TWO input readings and (Optionally) sends the computed value to an output device if the value breaks tolerance (+/-) boundaries (i.e. Value changes significantly).

| On Off Device Setup Screen
In1Dev | The Device Index to read a value from
Operator | (+)(-)(x)(/) plus, minus, times, divide or AVE-average
In2Dev | The Device Index to read a value from
Tolerenc | +/- Change Tolerance before setting Output
OutTode | The Tode Index of Out Device (optional) or 0-local
OutDev | The Device Index to SET the value on (optional)

Note: When OutTode is a Remote Tode; values are only sent every 14s when the In-Value passes +/- Tolerance of the last sent value.

5.2 Automation (Logic) :: Math :: Math Page -17-

## 6. System

The System menu allows one to do factory resets, enable MQTT, Soft Reset the unit and lookup the firmware version loaded. Pressing the Okay button on the FWver-???? entry causes the Soft Reset.

| System Sub-menu
USBSerial | What the Top USB plug is used for (auto-reboots)
Factry RST | Factory Reset
Pub ADiscv | Publish homie MQTT data for Auto-Discovery
SRFWv-???? | Soft Reset. Displays current Firmware verson.

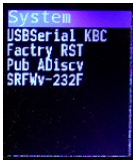
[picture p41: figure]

✔ USBSerial allows (3)options
◌ NOTICE: Changing the USB-Serial use causes an auto-reboot to occur.
- None = There is no USB Serial Usage (option for debugging)
- MQTT = Tode uses USB Serial to communicate with MQTT Server.
- KBC = Keyboard Control by Serial Input. (For Automated Testing)
- 8=up | 9=Set
- 4=left, 6=right
- 2=down 3=Get

✔ Factry RST erases all Todes and Devices and User-Settings.

✔ Pub ADiscv publishes ‘homie’ auto-discovery MQTT on-demand.
◌ only works when USBSerial=MQTT.

✔ SRFWv preforms a soft (no-erase) reset on-demand and also displays the loaded firmware version. It can be used to reset without power-cycling after making a new setting for USBSerial or any reason to do just a soft-reset.

6. System :: System :: System Page -18-

## 7. MQTT Control

Tode-RC firmware ver.232D+ has support for ‘homieMQTT’ Internet of Things(IoT) control using the Serial plug to connect a Tode to a Raspberry Pi IoT server.

### 7.1 Tode Setup

In SETUP System USBSerial set to ‘MQTT’. → → See 6.System for details.

### 7.2 OpenHab Server Setup

### 7.2.1 Openhabian

Download Raspberry-Pi Imager at https://www.raspberrypi.com/software/

When you run it; It'll ask for…
1. Operating System: scroll down and click "Other specific-purpose OS" ◌ Pick & Click "Home assistants and home automation"
◌ Pick & Click "openHAB"
- Pick 32-bit as OpenHAB states use 32-bit; works best.
- Storage: Choose the Flash-Card Target.
2. Insert Card into Raspberry-Pi and attach an Ethernet Cable
◌ Power the Raspberry Pi and wait a while for boot up process.
◌ Connect to the openHAB UI at http://openhabian:8080

7.2.1 MQTT Control :: OpenHab Server Setup :: Openhabian Page -19-

◌ This may take up to 45-Minutes to become available
◌ May have to use MS-DOS">arp -a" command to find it's IP-Address
◌ Enter an administrator Username and Password on Startup.
◌ Connect to the openHAB Log Viewer (frontail): http://openhabian:9001

### 7.2.2 Putty

3. Install PuttySSH Terminal on a Home PC.
a) See: https://putty.org/
b) Run the Putty terminal
- Click on Connection Type: SSH
- Enter Host Name: openhabian
- click open.
c) Login
- Username: openhabian
- Password: openhabian

### 7.2.3 MQTT Broker & Client

1. Login to the Server computer (Raspberry Pi) using ‘Putty’ terminal.
a) Install the MQTT Broker (Mosquitto) on the Raspberry Pi.
- See: https://community.openhab.org/t/oh3-mqtt-setup-and-configuration/111494 (https://community.openhab.org/t/oh3-mqtt-setup-and-configuration/111494)
openhabian:~$ sudo apt install mosquitto openhabian:~$ sudo systemctl start mosquitto openhabian:~$ sudo systemctl daemon-reload openhabian:~$ sudo systemctl enable mosquitto
b) Also install MQTT Client (mosquitto-clients) on the Raspberry Pi.
Openhabian:~$ sudo apt-get install mosquitto-clients
c) Visit the above link for enabling outside IP connections if desired.
2. Test the MQTT broker setup with mosquitto-clients.
a) Login with a 2nd putty terminal and enter

7.2.3 MQTT Control :: OpenHab Server Setup :: MQTT Broker & Client openhabian:~$ mosquitto_sub -v -t 'test/topic'
b) On the 1st putty terminal send an MQTT publish
openhabian:~$ mosquitto_pub -t 'test/topic' -m 'helloWorld'
verify that the (-m)message ‘helloWorld’ appears on the 2nd terminal.

✔ Online Instructions for installing an MQTT broker on Raspberry Pi.
◌ https://www.openhab.org/addons/bindings/mqtt/

### 7.2.4 Serial2MQTT

1. Install serial2mqtt
◌ See: https://github.com/TGit-Tech/Tode-RC-Firmware/tree/main/serial2mqtt_build (https://github.com/TGit-Tech/Tode-RC-Firmware/tree/main/serial2mqtt_build)
openhabian:~$ wget https://raw.githubusercontent.com/TGit-Tech/Tode-RC-Firmware/main/serial2mqtt_build/serial2mqtt.`arch`.zip

openhabian:~$ wget https://raw.githubusercontent.com/TGit-Tech/Tode-RC-Firmware/main/serial2mqtt_build/serial2mqtt.json

openhabian:~$ unzip serial2mqtt.`arch`.zip
openhabian:~$ mv Debug/serial2mqtt.`arch` serial2mqtt
2. Setup crontab to auto-run serial2mqtt at start-up
◌ Start the crontab editor
openhabian:~$ crontab -e
◌ Edit the file adding the following line at the bottom of the file.
@reboot /home/openhabian/serial2mqtt

be sure to save / write changes to file.

3. Check operation
a) Reboot (Power-Cycle) the Raspberry Pi Server.
b) Make sure ‘serial2mqtt’ starts after Raspberry Pi reboot
openhabian:~$ ps -x
PID TTY | STAT | TIME COMMAND
347 ? | Ss | 0:00 /bin/sh -c /home/openhabian/serial2mqtt
348 ? | Sl | 0:01 /home/openhabian/serial2mqtt
c) View the ‘serial2mqtt’ logfile
openhabian:~$ tail -f log.serial2mqtt.0.log

7.2.4 MQTT Control :: OpenHab Server Setup :: Serial2MQTT Page -21-d) For debugging; you can launch ‘serial2mqtt’ from the command line.
openhabian:~$ ~/serial2mqtt
e) Attach Tode to the Raspberry Pi by USB cable.
- Watch the ‘serial2mqtt’ log file as it connects and publishes data.

### 7.2.5 OpenHab

Inside OpenHab you can now add the MQTT binding which also requires an MQTT thing. Once the Tode publishes it’s ‘homie’ MQTT data the first time a ‘tode’ thing will show up in the ‘inbox’ feature.

However; due to OpenHab bugs after a ‘tode’ thing has been added one must instruct the Tode to send the ‘homie’ data a second time. Go to Todes SETUP menu, to ‘System’ menu and select ‘Pub ADiscv’ (stands for Publish Auto-Discovery data) and push the Okay button.

Only after OpenHab has received the ‘homie’ data a second time will the ‘channels’ show up. The rest of OpenHab setup should be instructed in the OpenHab guide.

The Tode publishes MQTT in the form of homie/tode/todename/devicename (gets) + /set for (sets).

It also publishes MQTT in the form of homie/tode/tstodename/tsdevicename where the ‘ts’ prefix stands for timestamped status. ‘ts’ channels are for (gets) only and appends a hexadecimal millisecond timestamp to the gotten value. ( example; ON-2fe3a1). Using OpenHab label card to show this (gotten) value ensures that the sets are preformed correctly. Watch that the timestamp changes after setting a new value.

A. MQTT /get Value Update

Once Widgets are setup to turn things on and off.
Using a Label Card to display “ts” values.
1. Get the UID of the MQTT Broker by clicking the ‘Copy UID’ symbol.

7.2.5 MQTT Control :: OpenHab Server Setup :: OpenHab Page -22-

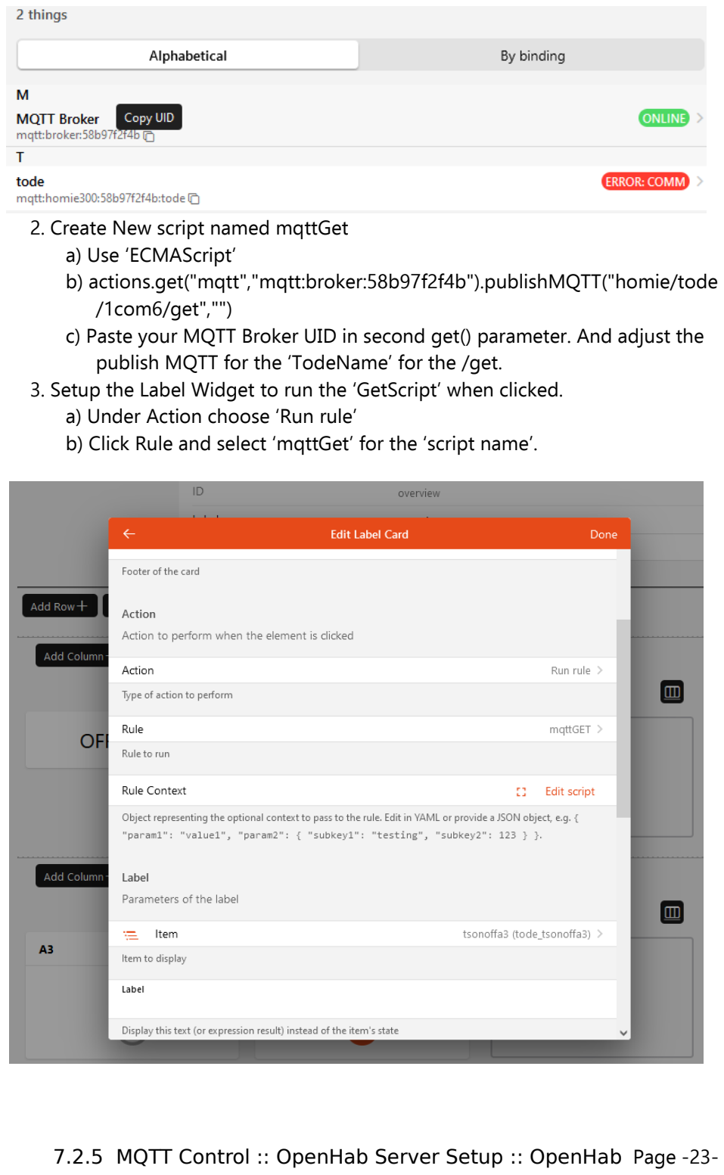
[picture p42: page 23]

2. Create New script named mqttGet
a) Use ‘ECMAScript’
b) actions.get("mqtt","mqtt:broker:58b97f2f4b").publishMQTT("homie/tode /1com6/get","")
c) Paste your MQTT Broker UID in second get() parameter. And adjust the publish MQTT for the ‘TodeName’ for the /get.
3. Setup the Label Widget to run the ‘GetScript’ when clicked.
a) Under Action choose ‘Run rule’
b) Click Rule and select ‘mqttGet’ for the ‘script name’.

7.2.5 MQTT Control :: OpenHab Server Setup :: OpenHab Page -23-

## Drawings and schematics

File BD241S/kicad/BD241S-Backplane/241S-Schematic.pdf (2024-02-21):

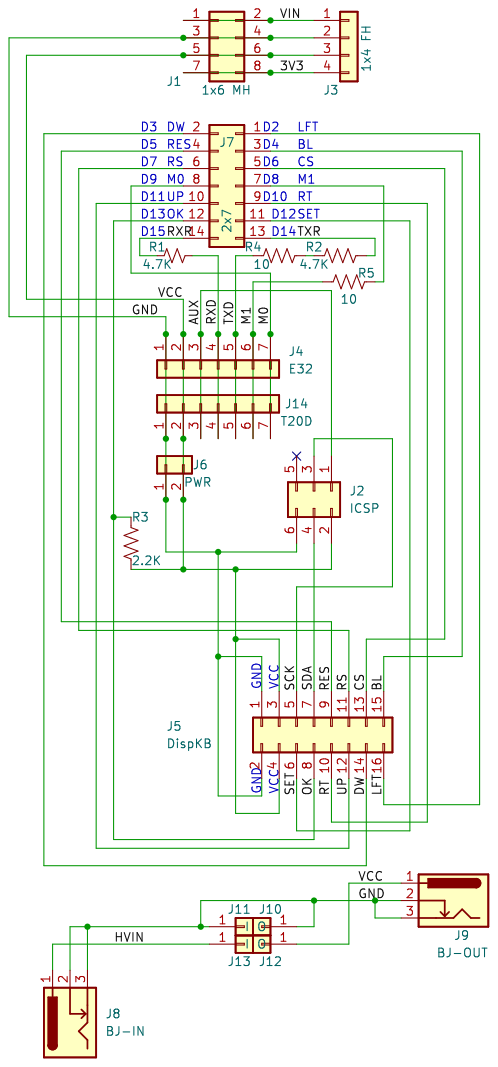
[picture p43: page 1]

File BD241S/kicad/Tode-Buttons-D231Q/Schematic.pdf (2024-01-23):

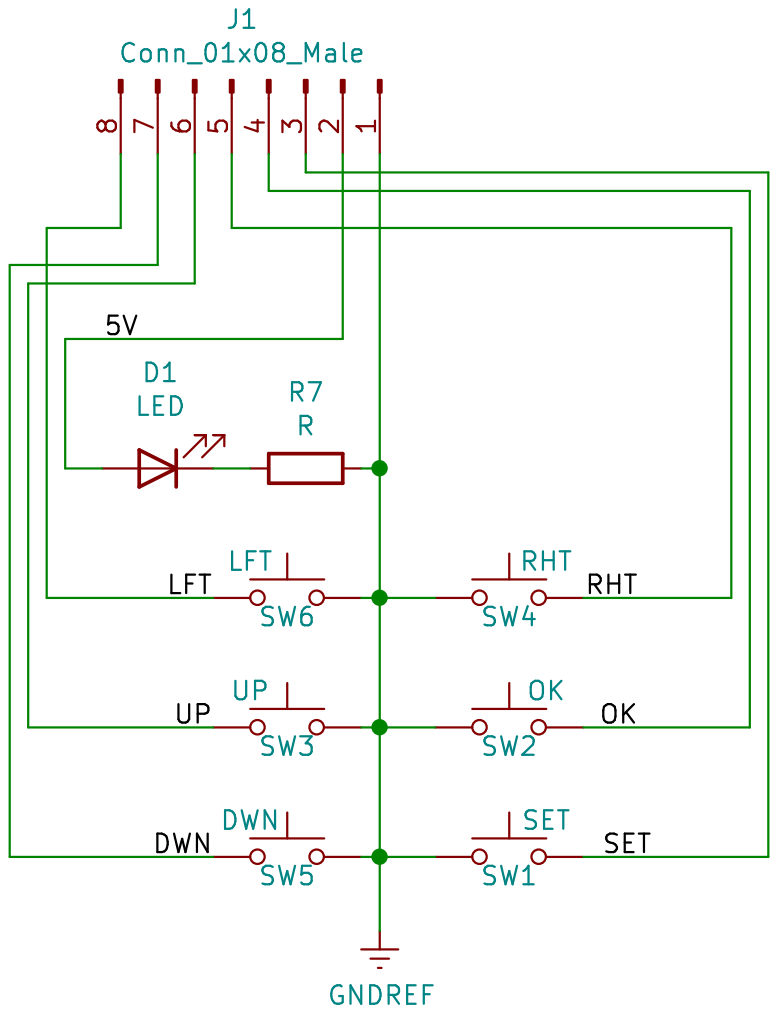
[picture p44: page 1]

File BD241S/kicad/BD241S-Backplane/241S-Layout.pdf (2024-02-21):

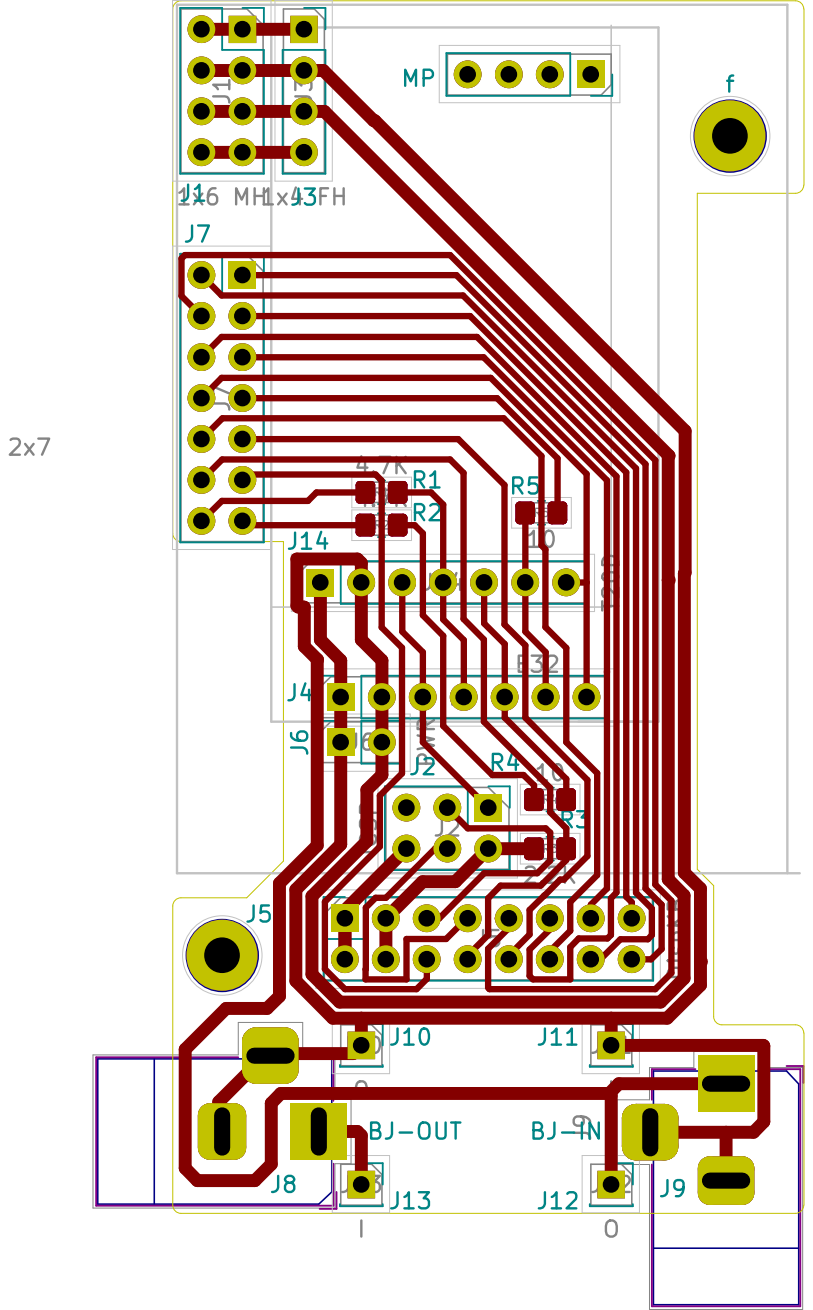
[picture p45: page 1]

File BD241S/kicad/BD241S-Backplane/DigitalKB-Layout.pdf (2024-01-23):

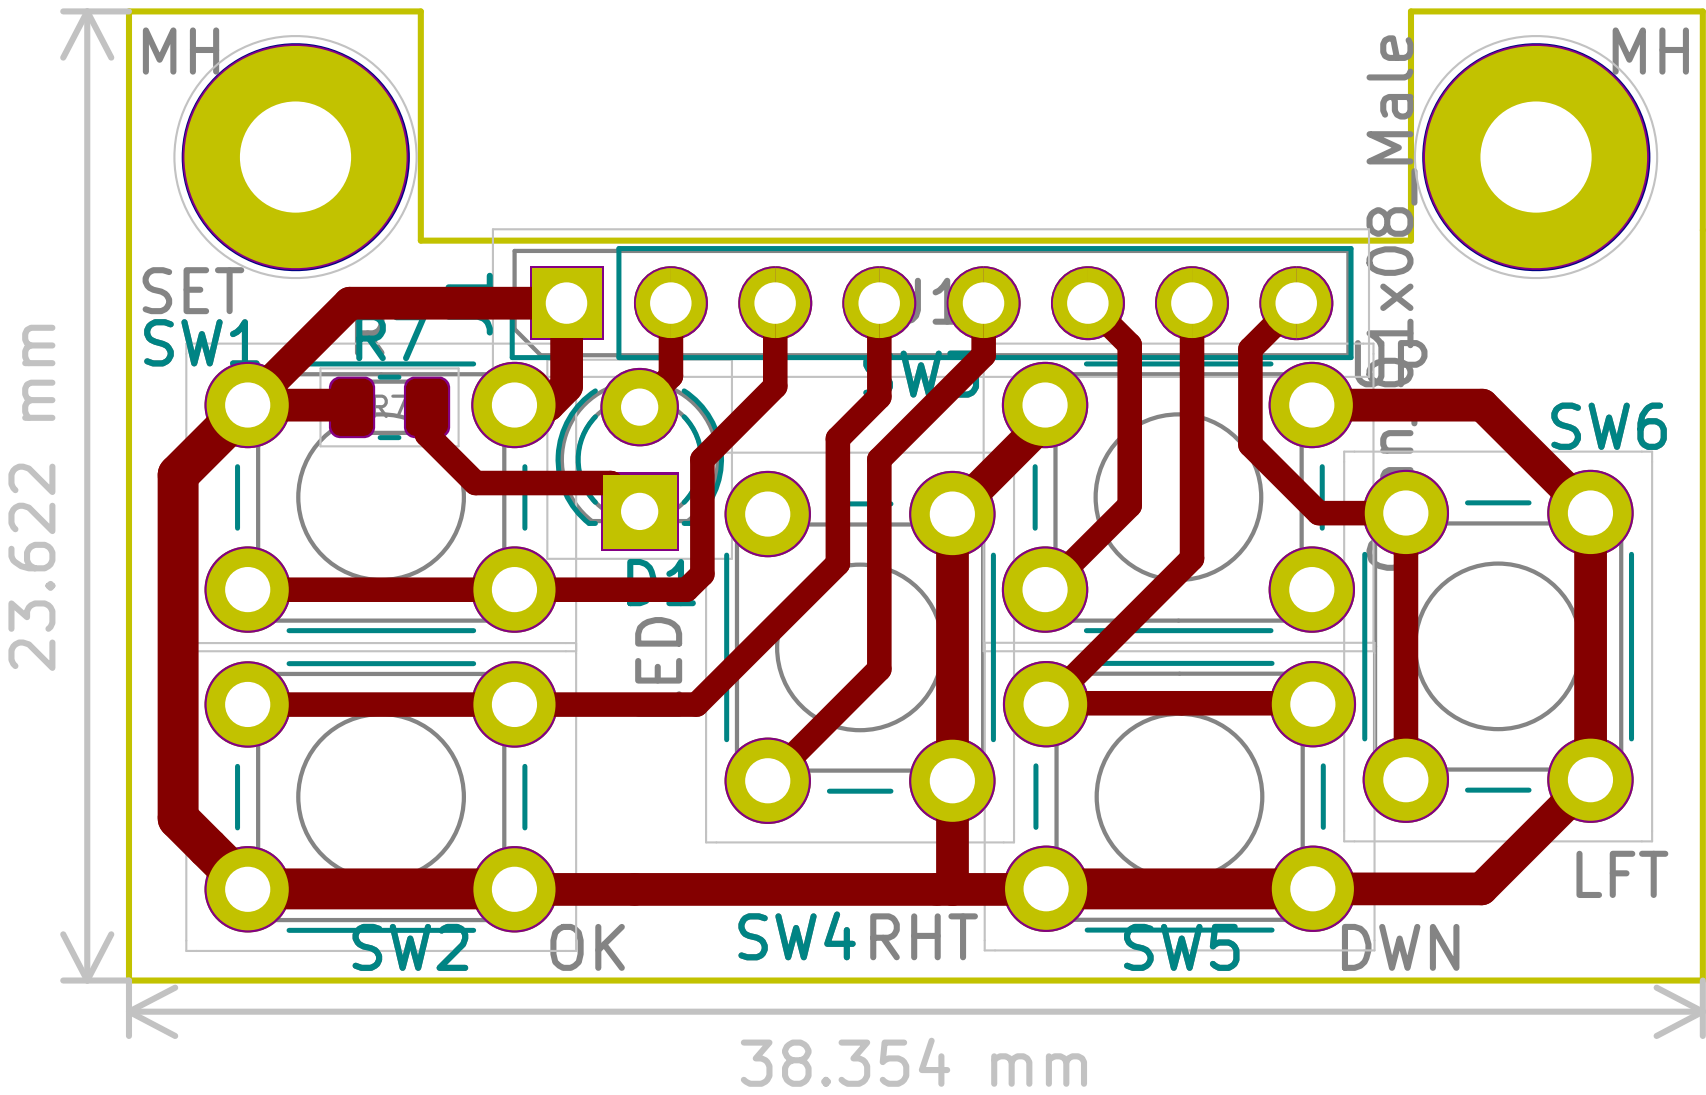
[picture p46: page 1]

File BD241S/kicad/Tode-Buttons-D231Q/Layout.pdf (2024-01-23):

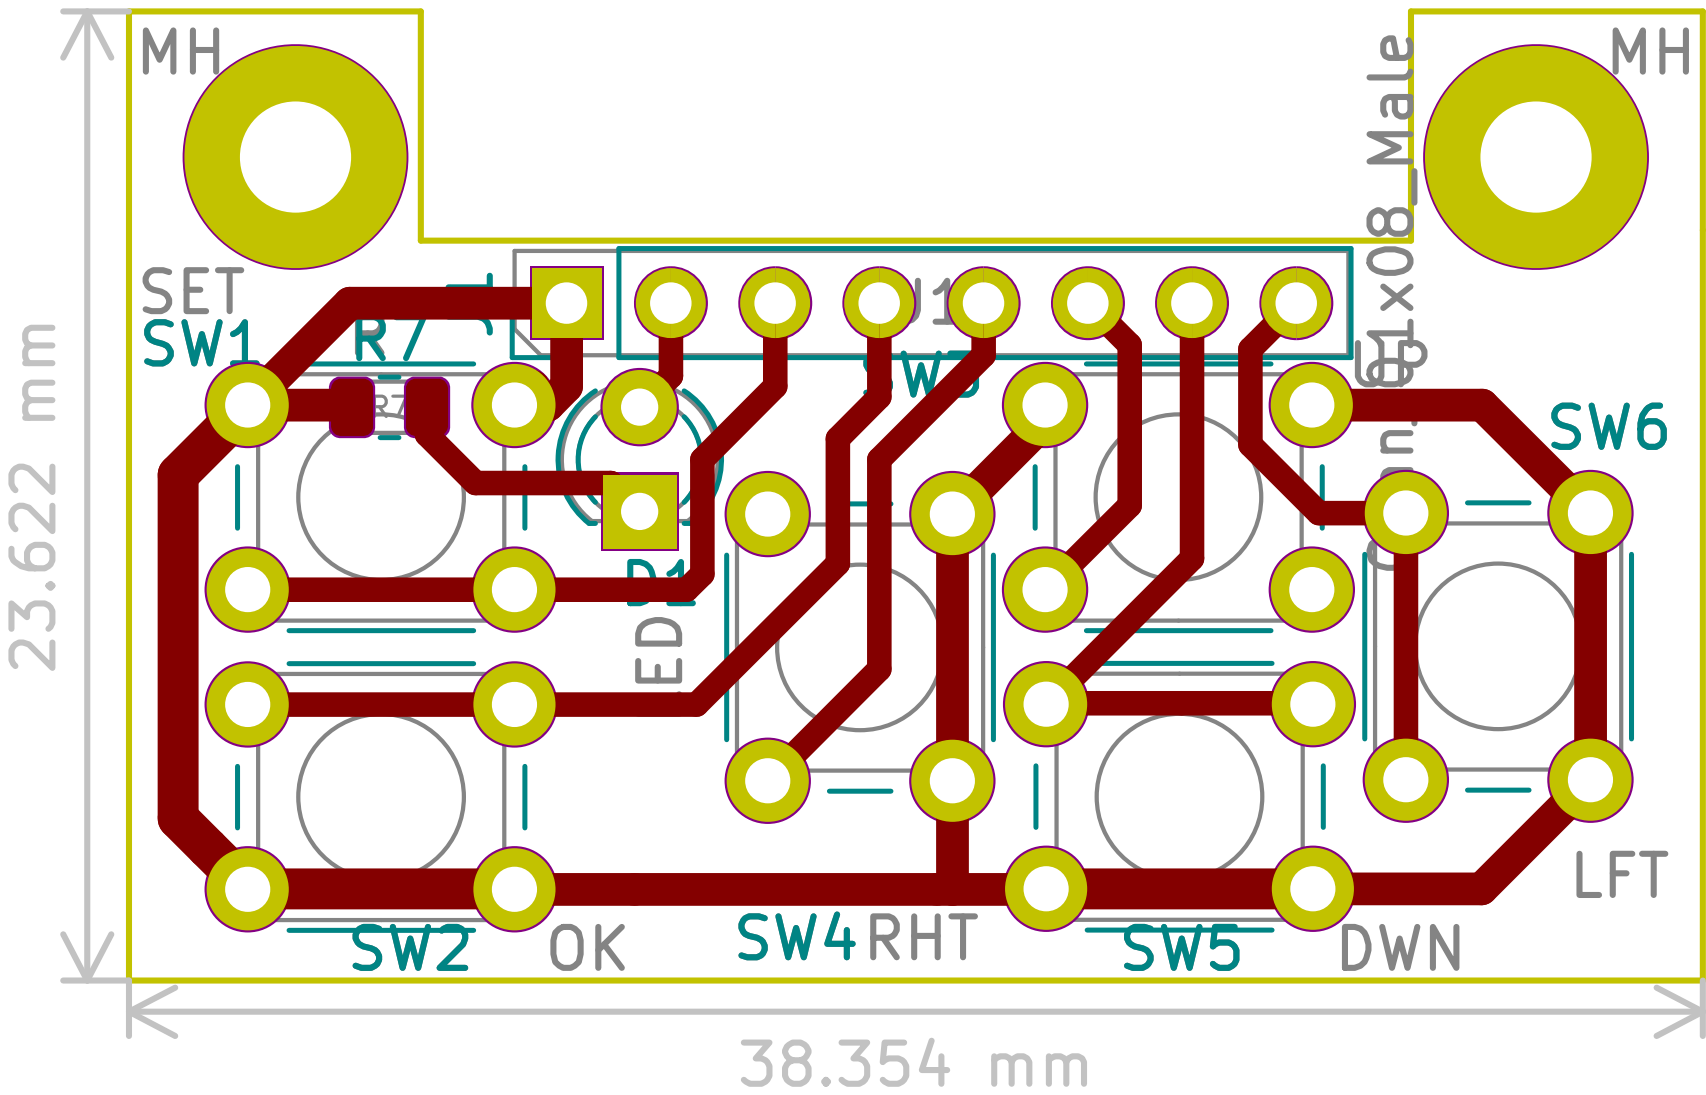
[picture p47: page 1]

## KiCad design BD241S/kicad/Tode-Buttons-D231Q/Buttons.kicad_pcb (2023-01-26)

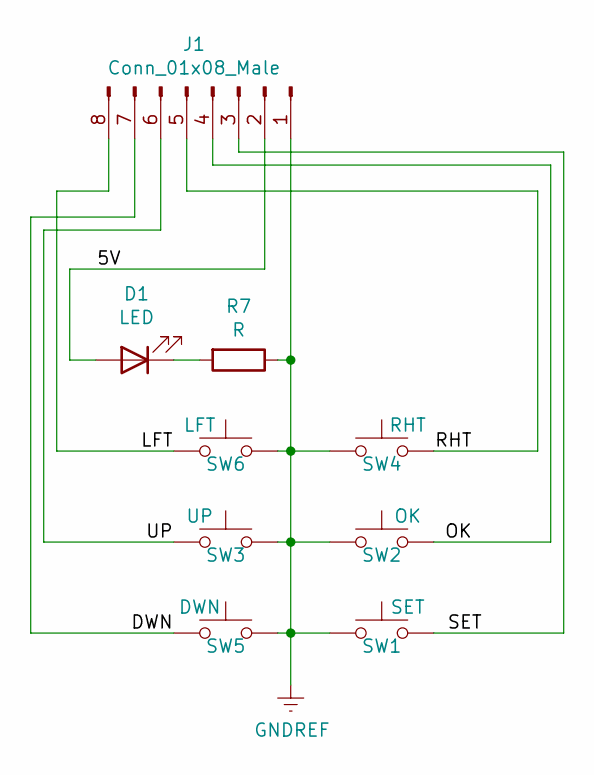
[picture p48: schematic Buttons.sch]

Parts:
D1: LED; LED_D3.0mm
J1: Conn_01x08_Male; PinHeader_1x08_P2.54mm_Vertical
R7: R; R_0805_2012Metric
SW1: SET; SW_PUSH_6mm
SW2: OK; SW_PUSH_6mm
SW3: UP; SW_PUSH_6mm
SW4: RHT; SW_PUSH_6mm
SW5: DWN; SW_PUSH_6mm
SW6: LFT; SW_PUSH_6mm

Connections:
/5V: D1.2 (A), J1.2
/DWN: J1.7, SW5.1
/LFT: J1.8, SW6.1
/OK: J1.4, SW2.2
/RHT: J1.5, SW4.2
/SET: J1.3, SW1.2
/UP: J1.6, SW3.1
GNDREF: J1.1, R7.1, SW1.1, SW2.1, SW3.2, SW4.1, SW5.2, SW6.2
unnamed: D1.1 (K), R7.2

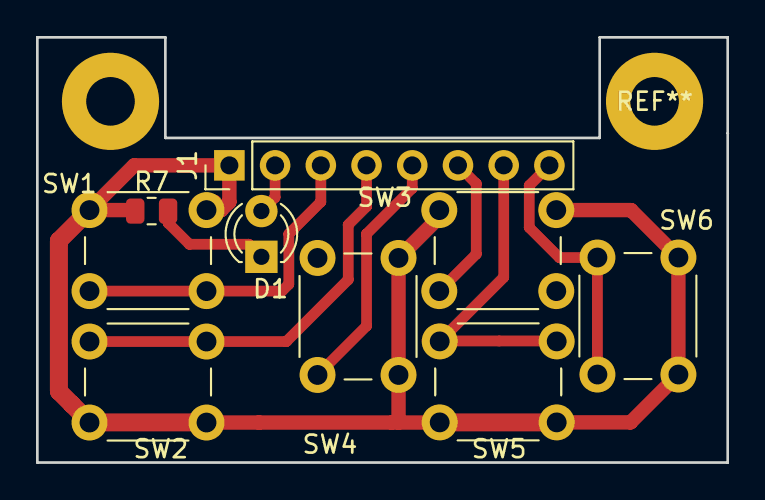
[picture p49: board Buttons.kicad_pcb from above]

Board: 2 copper layers, 38.4 x 23.6 mm, 9 parts (0 on the bottom side), 9 nets.

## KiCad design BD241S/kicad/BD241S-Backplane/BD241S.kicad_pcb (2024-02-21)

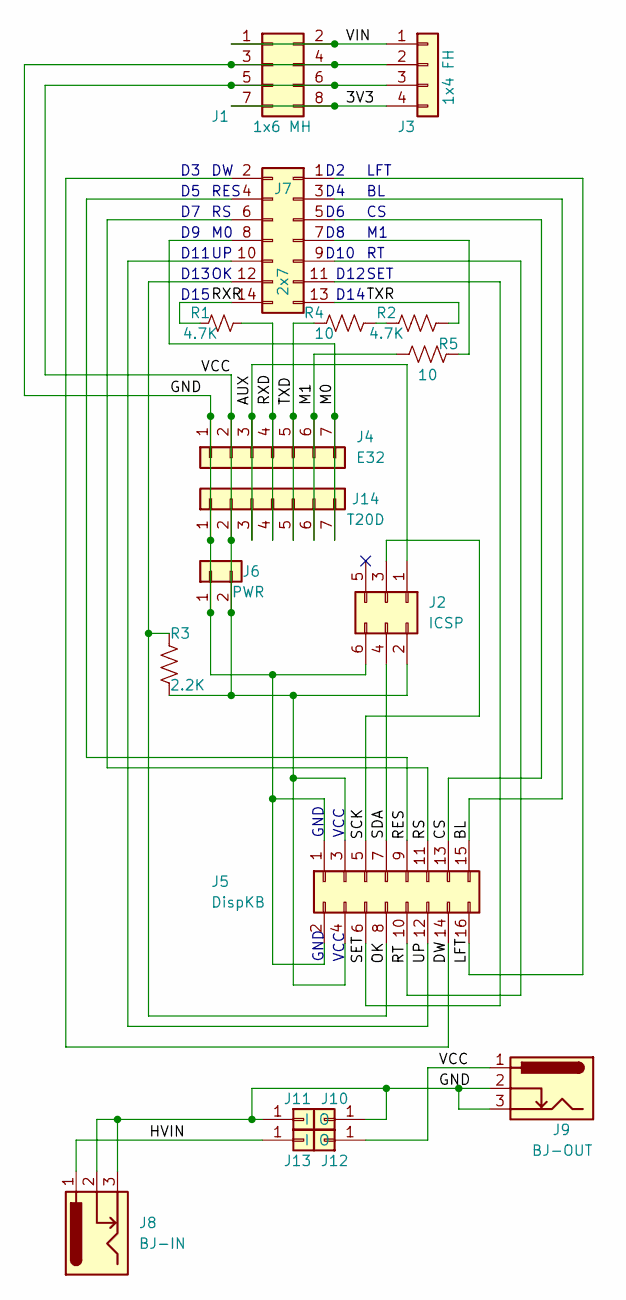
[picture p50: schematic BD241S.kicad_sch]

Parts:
J1: 1x6 MH; PinSocket_2x04_P2.54mm_Vertical
J2: ICSP; PinHeader_2x03_P2.54mm_Vertical
J3: 1x4 FH; PinSocket_1x04_P2.54mm_Vertical
J4: E32; PinSocket_1x07_P2.54mm_Vertical
J5: DispKB; PinSocket_2x08_P2.54mm_Vertical
J6: PWR; PinSocket_1x02_P2.54mm_Vertical
J7: 2x7; PinSocket_2x07_P2.54mm_Vertical
J8: BJ-IN; BarrelJack_Horizontal
J9: BJ-OUT; BarrelJack_Horizontal
J10, J12: O; PinSocket_1x01_P2.54mm_Vertical
J11, J13: I; PinSocket_1x01_P2.54mm_Vertical
J14: T20D; PinSocket_1x07_P2.54mm_Vertical
R1, R2: 4.7K; R_0805_2012Metric_Pad1.20x1.40mm_HandSolder
R3: 2.2K; R_0805_2012Metric_Pad1.20x1.40mm_HandSolder
R4, R5: 10; R_0805_2012Metric_Pad1.20x1.40mm_HandSolder

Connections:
/3V3: J1.7, J1.8, J3.4
/AUX: J2.1, J4.3, J14.3
/BL: J5.15, J7.3
/CS: J5.13, J7.5
/DW: J5.14, J7.2
/GND: J1.3, J1.4, J2.6, J3.2, J4.1, J5.1, J5.2, J6.1, J8.2, J8.3, J9.2, J9.3, J10.1, J11.1, J14.1
/HVIN: J8.1, J13.1
/LFT: J5.16, J7.1
/M0: J4.7, J7.8, J14.7
/M1: J4.6, J14.6, R5.1
/OK: J5.8, J7.12, R3.2
/RES: J5.9, J7.4
/RS: J5.11, J7.6
/RT: J5.10, J7.9
/RXD: J4.4, J14.4, R1.1
/RXR: J7.14, R1.2
/SCK: J2.3, J5.5
/SDA: J2.4, J5.7
/SET: J5.6, J7.11
/TXD: J4.5, J14.5, R4.1
/TXR: J7.13, R2.2
/UP: J5.12, J7.10
/VCC: J1.5, J1.6, J2.2, J3.3, J4.2, J5.3, J5.4, J6.2, J9.1, J12.1, J14.2, R3.1
/VIN: J1.1, J1.2, J3.1
unnamed: J7.7, R5.2
unnamed: R2.1, R4.2

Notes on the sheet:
GND
LFT
D13
RES
SET
D12
D15
VCC
D14
D10
D11

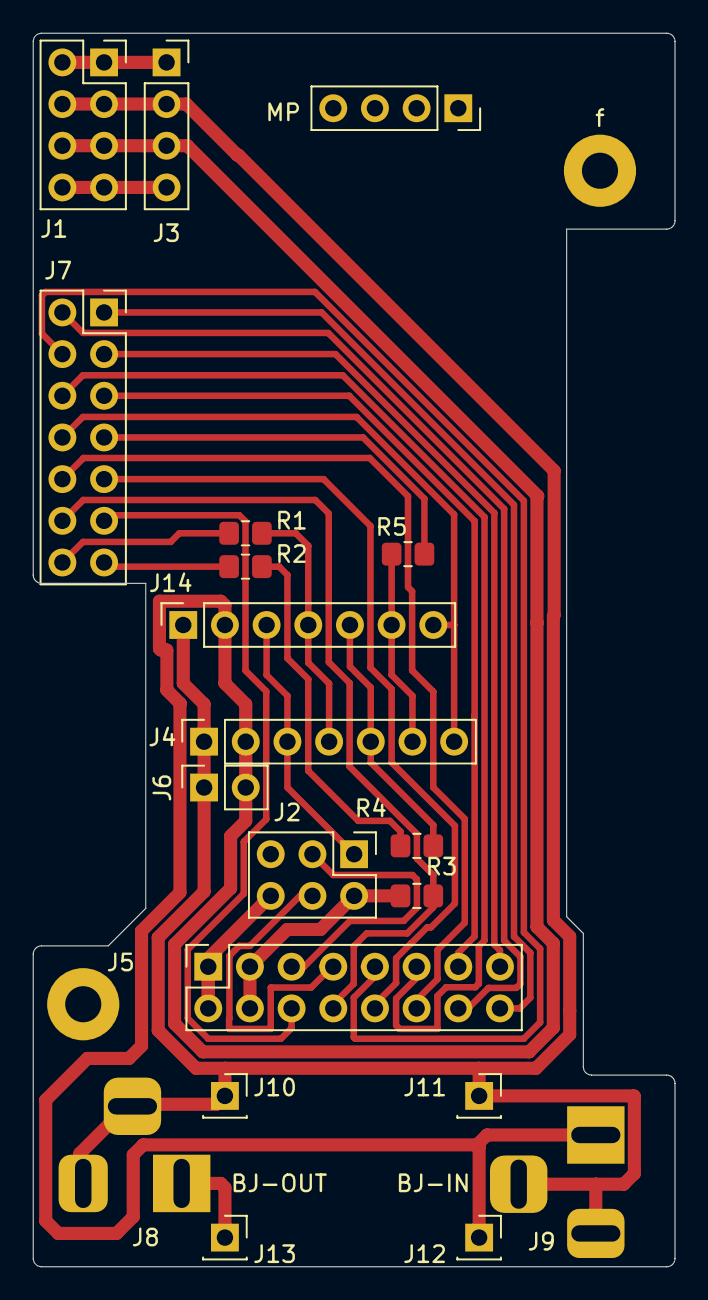
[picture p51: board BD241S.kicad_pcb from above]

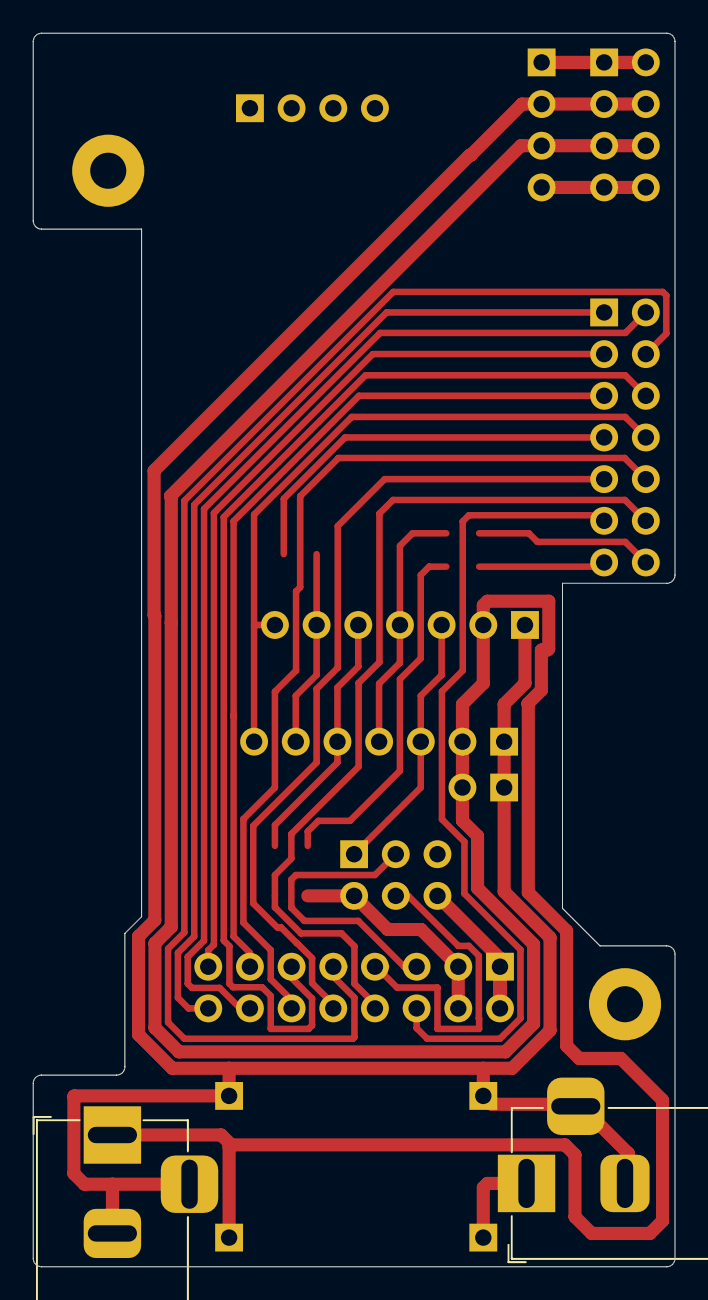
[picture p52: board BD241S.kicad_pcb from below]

Board: 2 copper layers, 39.1 x 75.2 mm, 22 parts (2 on the bottom side), 26 nets.

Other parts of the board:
MP: PinSocket_1x04_P2.54mm_Vertical
e: MountingHole_2.2mm_M2_Pad
f: MountingHole_2.2mm_M2_Pad

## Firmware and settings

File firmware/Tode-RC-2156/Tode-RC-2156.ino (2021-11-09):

/******************************************************************************************************************//**
 * @file      Tode-RC-212G.ino
 * @brief     Arduino Sketch for the Tode-RC System Implementing Ebyte E32 Transceiver.
 * @details 
 * @version   20CR [YYMD]
 * @bug       None Yet
 * @warning   Never call 'RF' object in Item Constructors
 * @copyright MIT Public License
 * @author    TGIT-TECH   original creation   2116
 **********************************************************************************************************************/
#include "lib/ABC.h"
#include "lib/ABC.cpp"
#include "Sys.h"

AnalogButtonCapture* ButtonCapture = 0;
Sys* System=0;

void setup() {
  
  pinMode(A15, INPUT_PULLUP);   // Pullup Analog Keypad-Pin
  pinMode(33, OUTPUT);          // RELAY-1
  pinMode(A11, OUTPUT);         // RELAY-2
  /*
  pinMode(A13, INPUT_PULLUP);   // 3-Wire Status ( Grounds on Run )
  digitalWrite(33, HIGH);
  digitalWrite(A11, HIGH);
  */
  pinMode(45, OUTPUT);          // ** For Pump VFD Speed Set **
  pinMode(48, OUTPUT);          
  digitalWrite(48, HIGH);       // Turn on Display Backlight
    
#if DEBUGLEVEL>0
  Serial.begin(115200);           // This has a funny way of blanking the display (Comment out to check)
  //Serial.begin(9600);           // This has a funny way of blanking the display (Comment out to check)
  while (!Serial) ;             // If the Serial Monitor isn't open at the time
#endif

  Serial1.begin(9600);          // Begin Radio Communication

  ButtonCapture = new AnalogButtonCapture(/*Pin*/A15, /*Debounce*/300, /*HoldRepeat*/2000, /*BuzzPin*/46);
  ButtonCapture->StartCapture();

  System = new Sys();
  System->Navigate( NAVKEYNONE );       // Required to Start the Display on Power-Up

}

void loop() {
  int iButton = ButtonCapture->Button();
  if ( iButton == 0 ) { DBERRORL(("iButton == 0")) }
  else { System->Loop( System->Navigate( iButton )); }
}

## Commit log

2020-11-02 Initial
    Initial Plans
    [Buttons.kicad_pcb, Buttons.sch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]
2020-11-27 Update
    Update
    [Buttons.kicad_pcb, Buttons.sch, Handheld-Backboard-E32-433T30D.kicad_pcb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]
2020-12-12 Updates
    Updates
    [Tode-CenterCover-Mega2560.skp, Tode-ScreenKeybCover-TFT1.77.skp]
2021-01-20 Buggy Firmware Update
    [EEPROMmap.ods, Tode-CenterCover-Mega2560.stl, Tode-ScreenKeybCover-TFT1.77.stl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]
2021-06-13 ver 2156
    Many Updates
    [AMPE32T30.kicad_pcb, AMPE32T30.sch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]
2021-11-09 Final Doc
    Final Doc
    [Tode-DispKB-Buttons.skp, Tode-DispKB-Buttons.stl, Tode-Handheld-AMPCenter.skp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]
2021-11-16 Doc Update
    Doc Update
    [Tode-Assembly.skp, Tode-DispKB-Cover.skp, Tode-DispKB-Cover.stl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]
2022-01-02 Button alignment Adjustments
    Model adjustments (minor). Reverse Compatible.
    [Tode-DispKB-Buttons.skp, Tode-DispKB-Buttons.stl, Tode-DispKB-Cover.skp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]
2022-01-26 CNC cut files in marked folder
    [AMPE32T30-Edge_Cuts.gbr, AMPE32T30-F_Cu.gbr, AMPE32T30-PTH.drl]
2023-01-26 Added Digital KB (DKB)
    Updated User Manual added Digital KB DKB
    [AMPE32T30.kicad_pcb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]
2024-01-23 Multi Model
    [2x7 x 6.5 PinHolder.stl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]
2024-02-21 SD23CF and BD241S
    Obsolete SA212K
    [2x7 x 6.5 PinHolder.stl, ALL-AMPCenter.skp, ALL-AMPCenter.stl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]
2024-12-30 Cleaned up scrap work
    Cleaned up scrap work
    [2x7 x 6.5 PinHolder.skp, ALL-AMPCenter.skp, ALL-AMPCenter.stl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]
